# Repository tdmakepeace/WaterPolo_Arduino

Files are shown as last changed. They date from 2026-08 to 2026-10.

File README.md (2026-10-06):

# Water Polo Scoreboard (Arduino Mega)

Operator scoreboard for water polo: **period clock**, **home/away scores**, and a **28 s shot clock**. The shot clock is shown on the local RGB matrix and 16×2 LCD, and is broadcast to external LoRa remote shot clocks (`lora_remote`).

---

## Parts list

| Qty | Part | Notes / SKU |
| --- | --- | --- |
| 1 | Arduino Mega 2560 (or compatible) | Required — Uno does not have enough pins |
| 1 | Waveshare RGB LED matrix 64×32 P3 | **SKU 33840** — RGB-Matrix-P3-64x32 (HUB75) |
| 1 | 5 V power supply for matrix | **≥ 2.5 A** (Waveshare rating); VH4 connector |
| 1 | HUB75 16-pin IDC ribbon | Usually included with the panel |
| 1 | VH4 2-pin power cable | Usually included with the panel |
| 1 | **Freenove I2C IIC LCD 1602** | Serial 16×2 “New Type” (I2C backpack onboard) |
| 16  | Momentary push-buttons | Score / clock / shot / TO / IN / Return / excl  |
| 1 | **5 V relay module** (or 5 V coil + driver) | Driven by **D12**; switches horn / siren / lamp |
| 1 | LoRa UART module (TX side) | e.g. DX-LR02 / DX-LR32 433 MHz class |
| 1+  | LoRa remote shot-clock units | Sketch `lora_remote/lora_remote.ino`. Wiring: [docs/lora_remote_build.md](docs/lora_remote_build.md) |
| — | Dupont / jumper wires, breadboard or proto  | As needed |
| — | USB cable (A–B) | Mega programming / optional 5 V for MCU only |

**Optional:** level shifter if LoRa module is strictly 3.3 V on UART. For a bare relay coil (no PCB module), use an NPN/MOSFET driver and a flyback diode across the coil — do **not** drive a coil from a Mega pin directly.

---

## What it does

| Control | Pin | Action |
| --- | --- | --- |
| Period start / stop  | **D2**  | Short press toggles countdown (shot clock follows) |
| Force shot 18 | **D3**  | Set shot clock to 18 s always (ignores <18 rule); **pauses** period clock |
| Exclusion | **D4**  | Start 18 s exclusion; **1st press** clock 1, **2nd press** clock 2; **pauses** period clock; applies **D5** if shot <18 |
| Shot → 18 | **D5**  | Set shot to 18 if <18; period clock **unchanged** (stays running or stopped) |
| Shot → 28 | **D6**  | Shot→28; period clock **unchanged**; **clears exclusions** |
| Timeout 1:00 | **D7**  | Pause period + shot; run independent 1:00 timeout |
| Interval 2:00 | **D8**  | Advance period (P1→P4); load match period length + shot→28; keep remaining exclusions; run **IN** or **HT** |
| Relay (horn / alarm) | **D12** | Pulses when shot expires (~0.5 s) or period hits 0 (~1 s) |
| Return | **D35** | End **TO/IN/HT** early → period+shot (**keeps shot value** after timeout); also **exits timing menu** |
| Period +1 s | **D36** | Short +1 s · long press **+10 s** (max 8:00) |
| Period −1 s | **D37** | Short −1 s · long press **−30 s** (min 0:00) |
| Shot +1 s | **D38** | Short +1 s · long press **+10 s** (max 28) |
| Shot −1 s | **D39** | Short −1 s · long press **−10 s** (min 0) |
| Home + | **D40** | Home score +1; **stops** period clock; shot → **28**; **clears exclusions** |
| Home − | **D41** | Decrease home |
| Away + | **D42** | Away score +1; **stops** period clock; shot → **28**; **clears exclusions** |
| Away − | **D43** | Decrease away |

- **D2** short press → start/stop immediately (play mode only; behaviour depends on **CLOCK** STOP / RUN / RUN-NS)  
- Hold **D2** ~3 s → STOP mode (from stopped): reload period to match length · RUN / RUN-NS: stop the period  
- Hold **D2 + D35** ~**3 s** → reload period to match length; **keep** shot + exclusions  
- Hold **D2 + D6** together for **3 s** → **full reset** (scores 0–0, period **P1** 8:00, shot 28, clear TO/IN/HT/exclusions, clocks stopped; timing values + **CLOCK** back to defaults)
- Hold **D5 + D6** ~**3 s** → **timing menu** (PERIOD → INTERVAL → HALFTIME → TIMEOUT → SHOT 28 → SHOT 18 → CLOCK; **D36**/**D37** ±30 s, shot pages ±1 s, or CLOCK cycle STOP → RUN → RUN-NS, **S/S** next/confirm, **D35** exit)  
- Operator detail: [timing menu](docs/user_guide_timing_menu.md) · [STOP mode](docs/user_guide_stop_mode.md) · [RUN mode](docs/user_guide_run_mode.md)  
- Shot clock counts while **play** is active (in STOP mode that matches the period; in RUN mode period may keep running alone)  
- If period remaining is **less than** the shot clock, the shot shows the period seconds (matrix / LCD / LoRa)  
- Value adjust buttons do **not** start/stop the clocks  
- Shot value is sent to LoRa remotes on every change, and **re-broadcast every 0.5 s while play is running**  
- **Period length:** default `PERIOD_SECONDS` (**8:00**). If you change the period clock **before the first START** of that period, the new value becomes the match length and is reloaded by **INTERVAL** / period-reload for later periods (e.g. trim to **6:30** before kickoff → every period starts at 6:30). Adjustments **after** START only fix the live clock and do not change later periods.  
- **Timeout:** period and shot freeze; when TO ends (or **D35 Return**), display returns to period+shot with **same shot value**; resume with **D2**  
- **Interval:** advances the period counter (max **P4**); loads the match period length / shot **28**; **remaining exclusion time is kept** (paused during the break, resumes next period); after **P2** uses half-time (`HALF_TIME_SECONDS`, currently **2:00**, label **HT**), otherwise `INTERVAL_SECONDS` (**2:00**, label **IN**); when the break ends (or **D35 Return**), display returns to period+shot; start play with **D2**. Also starts automatically when the period clock reaches **0:00** in **P1–P3** (not after **P4**).  
- **Exclusions:** one button (**D4**) starts clock 1 then clock 2; each slot starts only from idle (0) and cannot be restarted until it reaches 0; pause during timeout/interval and when play is stopped; remaining time is **carried into the next period** across IN/HT; a **goal** (home+ / away+) or **D6** (shot → 28) clears both clocks

---

## How to use

This is the operator overview for the control panel (button box + LCD). Full button-by-button detail lives in the mode guides below — use those when training operators or when **CLOCK** is set to **RUN** or **RUN-NS**.

**Detailed operator guides:**

| Guide | Contents |
|---|---|
| [Timing menu](docs/user_guide_timing_menu.md) | Open/leave menu; PERIOD / INTERVAL / HALFTIME / TIMEOUT / SHOT 28 / SHOT 18 / CLOCK |
| [STOP mode (Start/Stop)](docs/user_guide_stop_mode.md) | Every button when **CLOCK = STOP** (default) |
| [RUN mode](docs/user_guide_run_mode.md) | Every button when **CLOCK = RUN** or **RUN-NS** (running period clock) |

Panel layout reference:

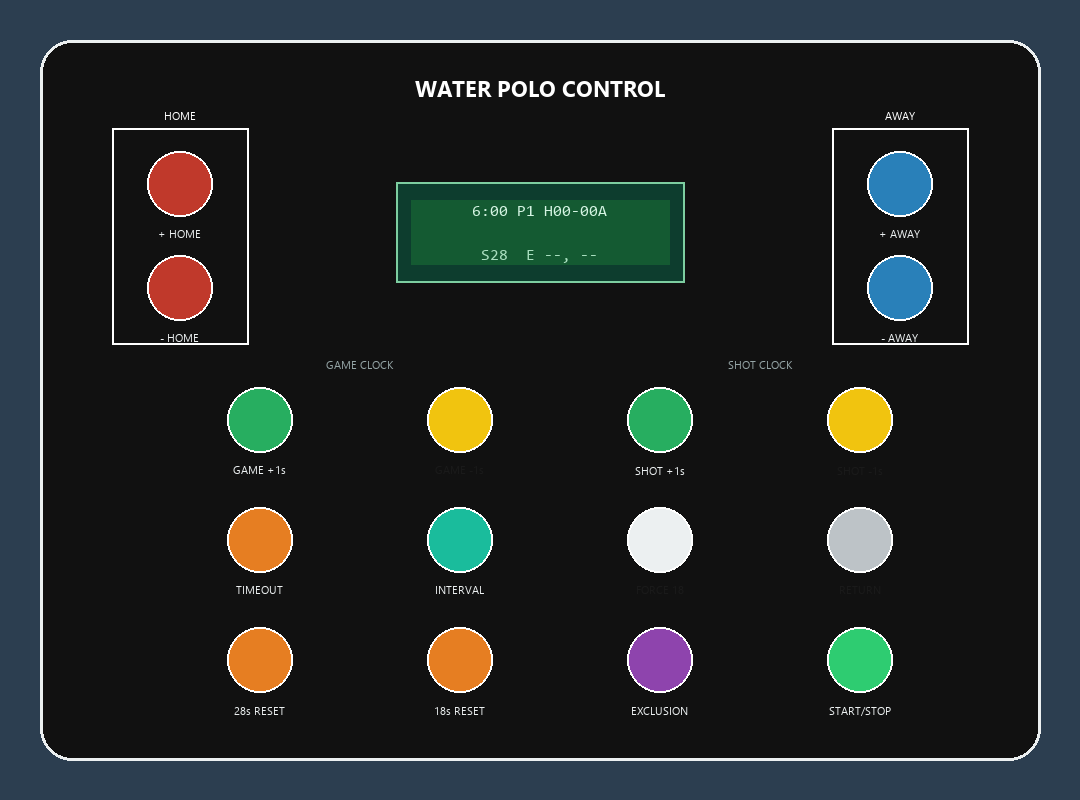
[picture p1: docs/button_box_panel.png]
Operator control panel button layout


Faceplate drill / 3D-print sizes (Ø16 mm buttons + Freenove 1602): `[docs/button_box_panel_measurements.md](docs/button_box_panel_measurements.md)`

### What you see

| Display | What it shows |
| --- | --- |
| LCD top line | Play: period time + `P#` + scores (`Hnn-nnA`). TO/IN/HT: break time + scores (no period) |
| LCD bottom line | Shot (`Snn`), run `*` (play active), exclusions `E-tt, tt`, command-ack `*` bottom-right |
| RGB matrix | Scores either side of `P#` (or `TO`/`IN`/`HT`), large centre clock, shot bottom-left, exclusions when active |

Defaults at power-up / full reset: scores **0–0**, period **P1** **8:00**, shot **28**, clocks **stopped**, **CLOCK = STOP**.

### Clock modes (STOP / RUN / RUN-NS)

Set on the timing-menu **CLOCK** page (see [timing menu guide](docs/user_guide_timing_menu.md)):

| Mode | Short **START/STOP** | Long **START/STOP** (~3 s) | Goal / EXCL / FORCE 18 / shot = 0 |
|---|---|---|---|
| **STOP** (default) | Toggle period + shot + exclusions together | From stopped: reload period to match length | Stops period + play |
| **RUN** | First start of quarter (or after timeout): start period + play. Later: toggle play only | Stops the period (+ play) | Period **keeps running**; play stops |
| **RUN-NS** | Same period rules as **RUN** | Same as **RUN** | Same as **RUN**, but shot clock disabled (hidden; shot buttons ignored) |

Hold **START/STOP** + **RETURN** ~**3 s** (either mode): reload period to match length; **keep** shot and exclusions; clocks stop.

### Start / stop (START/STOP) — STOP mode summary

| Action | Result |
| --- | --- |
| Short press **START/STOP** | Toggle period + shot + exclusions (play mode only) |
| While play runs | Period, shot, and exclusions count down |
| While play is stopped | Period, shot, and exclusions are frozen |
| Hold **START/STOP** ~3 s (from stopped) | Reset period clock to match length (does not start the clock) |

**START/STOP** does nothing during a timeout or interval / half-time — use **RETURN** first (or wait for the timer to finish).

For **RUN** / **RUN-NS** mode behaviour, see [docs/user_guide_run_mode.md](docs/user_guide_run_mode.md).

### Periods (P1–P4)

The board tracks the current period. Press **INTERVAL** at the end of a period to advance to the next (up to **P4**) and start the between-period break:

| Leaving | Break shown | Duration const (default) |
| --- | --- | --- |
| **P1** → **P2** | **IN** | `INTERVAL_SECONDS` (**2:00**) |
| **P2** → **P3** | **HT** | `HALF_TIME_SECONDS` (**2:00** for now; change to `5 * 60` for a 5-minute half-time) |
| **P3** → **P4** | **IN** | `INTERVAL_SECONDS` (**2:00**) |
| Already **P4**  | **IN** | stays on **P4**; same interval duration |

Full reset returns to **P1** and restores match length to **8:00**. Reloading the period clock (long-press **START/STOP** in STOP mode, or **START/STOP** + **RETURN**) does **not** change the period number.

### Scoring (HOME / AWAY)

| Button | Result (STOP mode) |
| --- | --- |
| **+ HOME** / **+ AWAY** | Score +1 (max 99); **stops** period + play; shot → **28**; **clears both exclusion clocks** |
| **− HOME** / **− AWAY** | Score −1 (min 0); clocks and shot are unchanged |

In **RUN** mode a goal still resets the shot and clears exclusions, but the **period keeps running**; only play stops. In **RUN-NS** the shot is disabled — goals only stop play and clear exclusions. Resume with **START/STOP**.

### Shot clock

| Button | Result (STOP mode) |
| --- | --- |
| **28s RESET** | Shot → **SHOT 28** length (default 28); run state unchanged; **clears both exclusion clocks** |
| **18s RESET** | Shot → **SHOT 18** length (default 18) only if current value is **shorter**; run state unchanged |
| **FORCE 18** | Shot → **SHOT 18** length always; **stops** period + play |
| Shot reaches **0** | Horn/relay (~0.5 s); remote buzzers; **clocks stop**; shot reloads to **SHOT 28** |

Lengths for **28s RESET** / **18s RESET** / **FORCE 18** are set on the timing-menu **SHOT 28** and **SHOT 18** pages.

In **RUN** mode, **FORCE 18** and shot expiry stop **play** only — the period keeps running.

When **period remaining** is less than the shot clock, the shot shows the period seconds on the matrix, LCD, and LoRa remotes. Period end takes precedence over shot expiry if both hit **0** together.

### Timeouts and intervals

| Button | Result |
| --- | --- |
| **TIMEOUT** | Pause period + play; run independent timeout (`TO`; length from menu) |
| **INTERVAL** | Advance period; load match length / **28**; keep exclusions; run **IN** or **HT** |
| **RETURN** short | End TO/IN/HT early (silent) → period + shot display |
| **RETURN** hold ~**3 s**  | During TO/IN/HT: end break **and** buzz. In play: buzz only |
| TO or IN/HT reaches **0** | Short horn/relay; display returns to period + shot automatically |

After timeout: shot value is **kept**; press **START/STOP** to resume.  
After interval / half-time: fresh period at match length / shot **28**; exclusions kept; press **START/STOP** to start play.

### Exclusions (EXCL)

| Button | Result (STOP mode) |
| --- | --- |
| **EXCL** (first press)  | Start exclusion **clock 1** (**18 s**); **stops** play; applies **18s RESET** rule if shot < 18 |
| **EXCL** (second press) | Start exclusion **clock 2** (same rules) while clock 1 is still running |

In **RUN** mode exclusions stop **shot/play** with the period still running (exclusions pause until **START/STOP**). In **RUN-NS** exclusions count down with the **period** clock.

Notes:

- Each slot starts only when it is **0** (idle). You cannot restart an active clock until it counts down to 0. If both are running, further presses do nothing.
- If clock 1 has expired and clock 2 is still running, the next press re-arms clock 1.
- Exclusion timers: **STOP** and **RUN** — tick with shot/play (pause when play stops and during TO/IN/HT). **RUN-NS** — tick with the period clock (pause during TO/IN/HT only).
- Remaining exclusion time is **carried into the next period** across **IN**/**HT** (auto at 0:00 or **INTERVAL**).
- A **goal** (**+ HOME** / **+ AWAY**) or **28s RESET** clears **both** exclusion clocks.
- Press **START/STOP** to resume play (and continue the exclusion countdown).

### PC-driven mode (WaterPoloScoreBoard over USB)

The Mega can act as a display + LoRa relay for the PC app [WaterPoloScoreBoard](https://github.com/tdmakepeace/WaterPoloScoreBoard). Plug the Mega's USB into the PC and pick its COM port on the app's **Settings** page. Matrix and LoRa wiring stay the same.

The app sends a newline-terminated frame at **9600** baud every **0.25 s**:

```text
HH,AA,PERIOD,CLOCK,SHOT,EX1,EX2      e.g. 03,01,P2,245,18,12,0
```

| Field | Meaning |
|---|---|
| `HH`, `AA` | Home / away score (0–99) |
| `PERIOD` | `P1`–`P4`, or `TO` / `IN` / `HT` |
| `CLOCK` | Period clock seconds; during `TO` / `IN` / `HT` the break countdown (shown in the large centre clock) |
| `SHOT` | Shot clock seconds |
| `EX1`, `EX2` | Exclusion clocks in seconds (`0` = hidden) |

- The **first valid frame** switches the board to PC-driven mode until power-cycle / reset: buttons and the local clocks are ignored, and the matrix and LCD show exactly what the PC sends. During `TO` the period clock shown bottom-right is the last value sent in play.
- The shot value is sent to the LoRa remotes when it changes and repeated every **0.5 s** while frames keep arriving (stops ~2 s after the PC goes quiet).
- Other lines from the PC are forwarded to LoRa unchanged: `BUZZER` (also pulses the D12 relay ~0.5 s), `END` / `CHANGE` (relay ~1 s), `TEST`, `exit`. Bare shot integers are ignored in PC-driven mode (the frame owns the shot); before the first frame they are relayed as-is, so the Mega also works as a plain LoRa relay.

### Timing menu (PERIOD / INTERVAL / HALFTIME / TIMEOUT / SHOT 28 / SHOT 18 / CLOCK)

Hold **18s RESET** and **28s RESET** for ~**3 s**. Clocks freeze while the menu is open. Values are kept until a **full reset** (not stored in EEPROM).

Full detail: [docs/user_guide_timing_menu.md](docs/user_guide_timing_menu.md)

| Order | Item | Default | Range |
|---|---|---|---|
| 1/7 | **PERIOD** | 8:00 | 0:30–15:00 (±30 s) |
| 2/7 | **INTERVAL** | 2:00 | 0:00–3:00 (±30 s) |
| 3/7 | **HALFTIME** | 2:00 | 0:00–7:00 (±30 s) |
| 4/7 | **TIMEOUT** | 1:00 | 0:30–5:00 (±30 s) |
| 5/7 | **SHOT 28** | 28 s | 1–60 s (±1 s) |
| 6/7 | **SHOT 18** | 18 s | 1–60 s (±1 s) |
| 7/7 | **CLOCK** | **STOP** | **STOP**, **RUN**, or **RUN-NS** (cycle) |

| Button | In menu |
|---|---|
| Game **+1s** / **−1s** | Current time **±30 s**, shot pages **±1 s**, or cycle **CLOCK** STOP → RUN → RUN-NS |
| **START/STOP** (LCD shows **S/S**) | Next item; on **CLOCK** confirm and **exit** |
| **RETURN** | Exit immediately (keeps changes already made) |

LCD: `SET PERIOD  1/7` / `8:00  S/S next`. Shot pages show `28s` / `18s`. Last page shows `S/S OK`. Other buttons are ignored until you leave the menu.

If the current period has not been started yet, changing **PERIOD** also updates the live period clock. **SHOT 28** / **SHOT 18** set the lengths used by **28s RESET**, **18s RESET**, **FORCE 18**, goals, interval, and shot expiry.

### Fine adjust (GAME CLOCK / SHOT CLOCK ±1s)

Use these to correct time without starting or stopping play yourself (they do not toggle the clocks):

| Button | Short press | Long press (~0.8 s) |
| --- | --- | --- |
| Game **+1s** | Period +1 s | Period **+10 s** |
| Game **−1s** | Period −1 s | Period **−30 s** |
| Shot **+1s** / **−1s** | Shot ±1 s | Shot ±10 s |

Limits: period **0:00–15:00** (live ±1 s; match length comes from the timing menu / pre-START trim), shot **0** to the current **SHOT 28** value. Period adjust only works in play mode (not during TO/IN). If you adjust period to **0:00**, the clocks stop.

If you change the period clock **before the first START** of the current period, that value becomes the **match length** used for later periods.

### Full game reset

Hold **START/STOP** and **28s RESET** together for **~3 s**:

- Scores → **0–0**
- Period → **P1** **8:00**, shot → **28**
- Timing lengths → defaults (period **8:00**, interval **2:00**, half-time **2:00**, timeout **1:00**, shot **28** / **18**)
- **CLOCK** → **STOP**
- Clears timeout / interval / half-time / exclusions / timing menu
- Clocks stopped

### Typical period workflow (STOP mode)

1. Confirm scores and clocks (or do a full reset). Optionally set **CLOCK** in the timing menu.
2. Press **START/STOP** to begin the period.
3. On a shot-clock reset foul / new possession → **28s RESET** (or **18s RESET** / **FORCE 18** as required).
4. On a goal → **+ HOME** or **+ AWAY** (clock stops, shot → 28, exclusions clear); resume with **START/STOP**.
5. On exclusion → **EXCL** (first press clock 1, second press clock 2), then **START/STOP** when play resumes.
6. Team timeout → **TIMEOUT**; when done (or **RETURN**), **START/STOP** to resume.
7. Between periods → **INTERVAL** (after **P2** this is **HT**); when done, **START/STOP** for the next period.
8. If the period hits **0:00**, the horn sounds (~1 s) and remotes get `END`. **P1–P3** then auto-start the **IN**/**HT** break (same as **INTERVAL**); **P4** stays at **0:00**.

For the **RUN** mode workflow, see [docs/user_guide_run_mode.md](docs/user_guide_run_mode.md).

### Button quick reference

| Panel label | Function |
| --- | --- |
| **START/STOP** | Start/stop (STOP: all clocks; RUN: see mode guide) |
| **+ HOME** / **− HOME** | Home score ±1 (+ also stops play, shot → 28, clears exclusions)  |
| **+ AWAY** / **− AWAY** | Away score ±1 (+ also stops play, shot → 28, clears exclusions)  |
| **28s RESET** | Shot → 28; clears exclusions |
| **18s RESET** | Shot → 18 if < 18 |
| **FORCE 18** | Shot → 18 always; stops play (period too in STOP mode) |
| **TIMEOUT** | Team timeout (length from menu) |
| **INTERVAL** | Next period + IN/HT break (fresh match length / 28; exclusions kept) |
| **RETURN** | Leave TO/IN/HT / menu; long ≈ buzz; with S/S ≈ period reload |
| **EXCL** | 18 s exclusion timers (press 1 → clock 1, press 2 → clock 2) |
| Game **+1s** | Period +1 s (hold **+10 s**); in timing menu **+30 s** / shot pages **+1 s** / CLOCK cycle |
| Game **−1s** | Period −1 s (hold **−30 s**); in timing menu **−30 s** / shot pages **−1 s** / CLOCK cycle |
| Shot **±1s** | Shot ±1 s (hold ±10 s) |
| Hold **18s + 28s** ~3 s | Timing menu (PERIOD / INTERVAL / HALFTIME / TIMEOUT / SHOT 28 / SHOT 18 / CLOCK) |
| Hold **S/S + 28s** ~3 s | Full game reset |
| Hold **S/S + RETURN** ~3 s | Reload period length; keep shot + exclusions |

---

## Libraries

Matrix driver files are **vendored** in `waterpolo_scoreboard/`: `RGBmatrixPanel`, `Adafruit_GFX`, `gamma.h`, `gfxfont.h`, `glcdfont.c`, `Fonts/fonts.h`. The sketch calls Waveshare `Reginit()` **before** `matrix.begin()`. You do not need the Library Manager Adafruit GFX / RGB matrix Panel packages for the scoreboard sketch.

Arduino IDE → **Tools → Manage Libraries**:

1. **LiquidCrystal I2C** (e.g. by Frank de Brabander), or Freenove’s `LiquidCrystal_I2C.zip` from their kit docs

**Board:** Tools → Board → **Arduino Mega or Mega 2560**

I2C address: sketch tries **0x27** (PCF8574T), then **0x3F** (PCF8574AT) automatically.

---

## Full Arduino Mega pin map

Status legend: **USED** = wired by this project · **RESERVED** = claimed by the matrix library (leave free) · **SPARE** = available for expansion · **AVOID** = prefer not to use

### Digital pins D0–D53

| Pin | Status | Connection / notes |
| --- | --- | --- |
| D0  | AVOID | Serial RX0 (USB serial) — leave free for programming/debug |
| D1  | AVOID | Serial TX0 (USB serial) — leave free for programming/debug |
| D2  | USED | Button — period clock start / stop |
| D3  | USED | Button — **force shot → 18** (pauses period clock) |
| D4  | USED | Button — **exclusion** (18 s, no reset; 1st press clock 1, 2nd press clock 2) |
| D5  | USED | Button — shot clock → 18 s (if < 18) |
| D6  | USED | Button — shot clock → 28 s (clears exclusions) |
| D7  | USED | Button — **timeout 1:00** |
| D8  | USED | Button — **interval / half-time** (advances period) |
| D9  | USED | Matrix HUB75 **LAT / STB** |
| D10 | USED | Matrix HUB75 **OE** |
| D11 | USED | Matrix HUB75 **CLK** (must be on PORTB) |
| D12 | USED | **5 V relay** IN (default HIGH = ON; see `RELAY_ACTIVE_HIGH`) |
| D13 | SPARE | Also onboard LED — usable if LED flash is acceptable |
| D14 | SPARE | Serial3 TX — free unless you need Serial3 |
| D15 | SPARE | Serial3 RX — free unless you need Serial3 |
| D16 | SPARE | Serial2 TX — free unless you need Serial2 |
| D17 | SPARE | Serial2 RX — free unless you need Serial2 |
| D18 | USED | LoRa module **RX** ← Mega **TX1** (Serial1) |
| D19 | USED | LoRa module **TX** → Mega **RX1** (Serial1) |
| D20 | USED | Freenove LCD **SDA** (I2C) |
| D21 | USED | Freenove LCD **SCL** (I2C) |
| D22 | RESERVED | Matrix library (PORTA) — **do not use** |
| D23 | RESERVED | Matrix library (PORTA) — **do not use** |
| D24 | USED | Matrix HUB75 **R1** |
| D25 | USED | Matrix HUB75 **G1** |
| D26 | USED | Matrix HUB75 **B1** |
| D27 | USED | Matrix HUB75 **R2** |
| D28 | USED | Matrix HUB75 **G2** |
| D29 | USED | Matrix HUB75 **B2** |
| D30 | SPARE | Was parallel LCD RS — free with I2C LCD |
| D31 | SPARE | |
| D32 | SPARE | |
| D33 | SPARE | |
| D34 | SPARE | Was interval — now **D8** |
| D35 | USED | Button — **RETURN** (end TO/IN) |
| D36 | USED | Button — period clock **+1 s** (long **+10 s**) |
| D37 | USED | Button — period clock **−1 s** (long **−30 s**) |
| D38 | USED | Button — shot clock **+1 s** |
| D39 | USED | Button — shot clock **−1 s** |
| D40 | USED | Button — home score + |
| D41 | USED | Bu tton — home score − |
| D42 | USED | Button — away score + |
| D43 | USED | Button — away score − |
| D44 | SPARE | PWM-capable |
| D45 | SPARE | PWM-capable |
| D46 | SPARE | |
| D47 | SPARE | |
| D48 | SPARE | |
| D49 | SPARE | |
| D50 | SPARE | SPI MISO — free unless using SPI |
| D51 | SPARE | SPI MOSI — free unless using SPI |
| D52 | SPARE | SPI SCK — free unless using SPI |
| D53 | SPARE | SPI SS — free unless using SPI |

### Analog pins A0–A15 (also usable as digital)

| Pin | Status | Connection / notes |
| --- | --- | --- |
| A0  | USED | Matrix HUB75 address **A** |
| A1  | USED | Matrix HUB75 address **B** |
| A2  | USED | Matrix HUB75 address **C** |
| A3  | USED | Matrix HUB75 address **D** |
| A4  | SPARE  | |
| A5  | SPARE  | |
| A6  | SPARE  | |
| A7  | SPARE  | |
| A8  | SPARE  | |
| A9  | SPARE  | |
| A10 | SPARE  | |
| A11 | SPARE  | |
| A12 | SPARE  | |
| A13 | SPARE  | |
| A14 | SPARE  | |
| A15 | SPARE  | |

### Spare pins summary (quick list)

**Digital:** D13, D14, D15, D16, D17, D30, D31, D32, D33, D34, D44, D45, D46, D47, D48, D49, D50, D51, D52, D53  

**Analog / digital:** A4, A5, A6, A7, A8, A9, A10, A11, A12, A13, A14, A15  

**Do not use:** D0, D1 (USB serial), D22, D23 (matrix library)

---

## Wiring diagram

### Operator control panel

Suggested faceplate layout for the operator box (buttons + I2C LCD):

Operator control panel button layout

**3D-print / CNC measurements** (Ø16 mm buttons + Freenove I2C LCD 1602): see `[docs/button_box_panel_measurements.md](docs/button_box_panel_measurements.md)` — panel **250 × 180 mm**, LCD bezel cutout **72 × 25 mm**, full hole-centre table and SVG. Printable mesh: `[docs/button_box_panel_faceplate.stl](docs/button_box_panel_faceplate.stl)`.

| Position | Control | Pin |
| --- | --- | --- |
| Top left | Home + / − | **D40** / **D41** |
| Top right | Away + / − | **D42** / **D43** |
| Center | I2C LCD 16×2 | **SDA D20** / **SCL D21** |
| Row 1 (under LCD) | Game +1s · Game −1s · Shot +1s · Shot −1s | **D36** · **D37** · **D38** · **D39** |
| Row 2 | Timeout · Interval · Force 18 · Return | **D7** · **D8** · **D3** · **D35** |
| Row 3 | 28s Reset · 18s Reset · Exclusion · Start/Stop | **D6** · **D5** · **D4** · **D2** |

### RGB matrix → Mega (HUB75)

Confirmed for **Waveshare RGB-Matrix-P3-64x32** (SKU **33840**) with the vendored Waveshare `RGBmatrixPanel` driver on **Arduino Mega 2560** — pin numbers and ribbon colours match the working `waterpolo_scoreboard/` sketch. Data lines **R1…B2** are fixed on **D24–D29** (`PORTA`); address **A0–A3**, **CLK D11**, **LAT D9**, **OE D10**. Rainbow ribbon: **yellow #14 → LAT D9**, **green #15 → OE D10**. Pin 8 on this 64×32 HUB75 is **GND** (grey #8) — not address **E**.

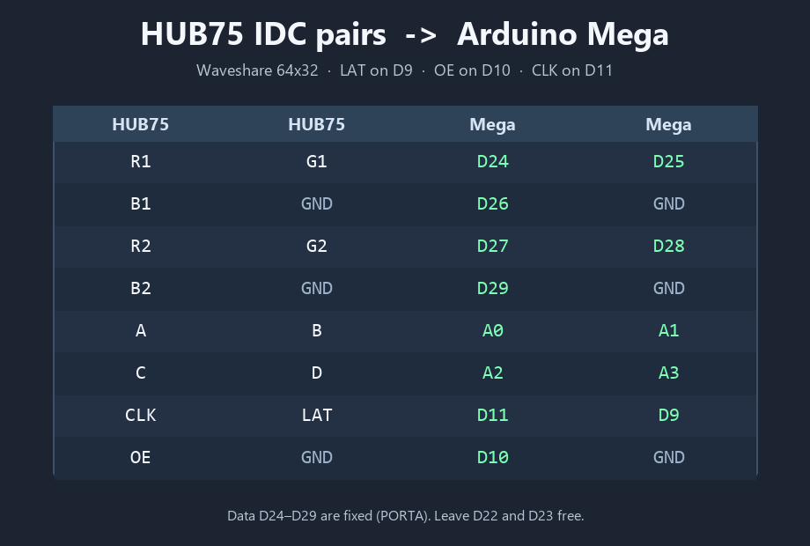
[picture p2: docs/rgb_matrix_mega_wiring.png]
RGB Matrix HUB75 wiring to Arduino Mega


HUB75 IDC pairs (as on the connector) → Mega:

| HUB75 | Mega | HUB75 | Mega |
| ----- | --- | --- | --- |
| R1 | **D24** | G1 | **D25** |
| B1 | **D26** | GND | **GND** |
| R2 | **D27** | G2 | **D28** |
| B2 | **D29** | GND | **GND** |
| A | **A0**  | B | **A1**  |
| C | **A2**  | D | **A3**  |
| CLK | **D11** | LAT / STB | **D9**  |
| OE | **D10** | GND | **GND** |

Power: **VH4 VCC / GND** → **external 5 V ≥2.5 A PSU** (not Mega 5 V).

Leave **D22** and **D23** free — the matrix library writes the full `PORTA` register.

#### Rainbow ribbon colours (16-way, brown = pin 1)

On a rainbow flat IDC ribbon, **brown is conductor 1** (= HUB75 **R1**). Align the brown edge with the pin-1 mark on the HUB75 header (often a triangle / arrow on the moulding). Colours then follow in order:

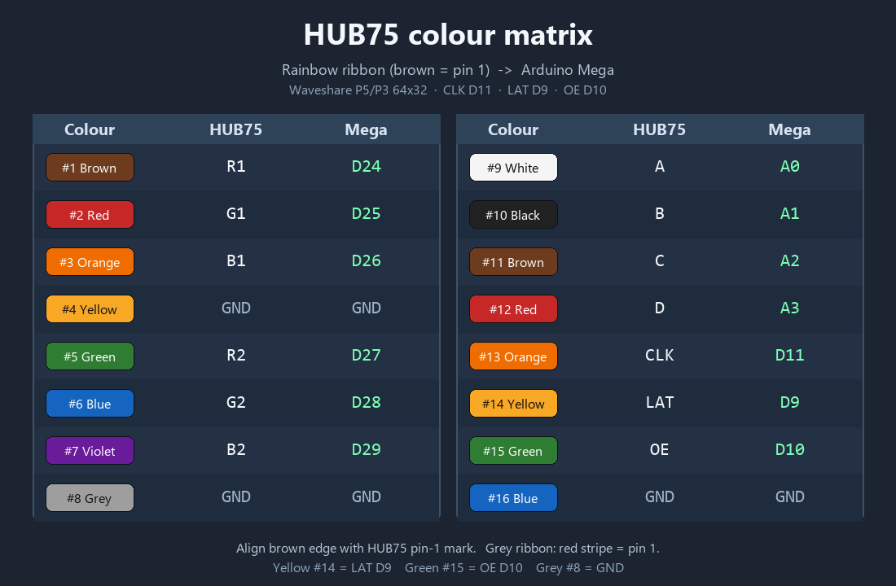
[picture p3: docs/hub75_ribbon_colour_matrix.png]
HUB75 rainbow ribbon colour matrix


| # | Colour | HUB75 | Mega |
| --- | --- | ----- | --- |
| 1 | Brown  | R1 | **D24** |
| 2 | Red | G1 | **D25** |
| 3 | Orange | B1 | **D26** |
| 4 | Yellow | GND | **GND** |
| 5 | Green  | R2 | **D27** |
| 6 | Blue | G2 | **D28** |
| 7 | Violet | B2 | **D29** |
| 8 | Grey | GND | **GND** |
| 9 | White  | A | **A0** |
| 10  | Black  | B | **A1** |
| 11  | Brown  | C | **A2** |
| 12  | Red | D | **A3** |
| 13  | Orange | CLK | **D11** |
| 14  | Yellow | LAT | **D9** |
| 15  | Green  | OE | **D10** |
| 16  | Blue | GND | **GND** |

Grey ribbons with a **red stripe** mark pin 1 the same way (stripe = R1 / brown above).

### Full system overview

```text
                         +---------------------------+
                         |     5 V / ≥2.5 A PSU      |
                         |  (+) -------------- (-)   |
                         +-------|------|------+-----+
                                 |      |
                                 |      +---- common GND ----+
                                 |                           |
                                 v                           v
                    +------------------------+      +------------------+
                    | Waveshare 64x32 Matrix |      |  Arduino Mega    |
                    | VH4: VCC / GND         |      |  2560            |
                    | HUB75 INPUT (IDC)      |      |                  |
                    +-----------+------------+      |  USB (PC)        |
                                |                   |                  |
           HUB75 ribbon                                         |                   |  Buttons         |
                                |                   |  Relay D12       |
                                |                   |  I2C LCD 20/21   |
                                |                   |  Serial1 18/19   |
                                v                   +--------+---------+
                    R1->24  G1->25  B1->26                   |
                    R2->27  G2->28  B2->29                   |
                    A->A0   B->A1   C->A2   D->A3            |
                    LAT->9  OE->10 CLK->11  GND->GND        |
                                                             |
              +------------------+     +---------------------+--+
              | Freenove I2C     |     | LoRa TX module       |
              | LCD 1602         |     | RX  <- Mega 18 (TX1) |
              | GND -> GND       |     | TX  -> Mega 19 (RX1) |
              | VCC -> 5V        |     | GND <-> Mega GND     |
              | SDA -> 20        |     | VCC = 3V3/5V (datasheet) |
              | SCL -> 21        |     +----------+-----------+
              +------------------+                |
                                                  |  RF @ 433 MHz
                                                  v
                                               LoRa remotes
                                               (lora_remote)

  Buttons (each: Mega pin ----- button ----- GND)
    D2  period start/stop
    D3  force shot 18
    D4  exclusion (press 1 → clock 1, press 2 → clock 2)
    D5  shot → 18 (if < 18)     D6  shot → 28
    D7  timeout 1:00
    D8  interval 2:00  D35 RETURN
    D36 period +1s (+10 long)    D37 period -1s (-30 long)
    D38 shot +1s      D39 shot -1s
    D40 home+     D41 home-
    D42 away+     D43 away-

  Relay (5 V module — preferred):
    Mega 5V  ----- VCC (JD-VCC jumper on if module supports it)
    Mega GND ----- GND
    Mega D12 ----- IN   (signal)
    COM/NO/NC ---- wire to your horn / siren / lamp supply (isolated from Mega)

  Bare 5 V relay coil (not recommended without a driver):
    Use a transistor or MOSFET + flyback diode across the coil.
    Mega pin cannot source coil current safely.

  If the module is "active LOW" (LED on when IN is grounded), set in the sketch:
    const bool RELAY_ACTIVE_HIGH = false;
```

### Power rules

1. Power the **matrix from the external 5 V supply** on the **VH4** connector — never from the Mega 5 V pin.
2. Tie **PSU GND**, **Mega GND**, **matrix GND**, **LCD GND**, **LoRa GND**, and **button commons** together.
3. Mega may be powered by USB during development; for stand-alone use a separate Mega supply (USB power bank / VIN) is fine.

---

## Build & upload instructions

1. **Assemble power first** — connect the matrix VH4 cable to the 5 V / ≥2.5 A supply and common GND **before** plugging in the HUB75 ribbon for long sessions.
2. **Wire HUB75** exactly as in the pin map (data lines **must** be 24–29).
3. **Wire buttons** D2–D8, D35–D43 to GND (internal pull-ups; pressed = LOW).
4. **Wire Freenove I2C LCD** — **GND→GND**, **VCC→5V**, **SDA→D20**, **SCL→D21**. Contrast/backlight are onboard (no pot needed).
5. **Wire the 5 V relay** to **D12** (see relay wiring above). Set `RELAY_ACTIVE_HIGH` to match your module.
6. **Wire LoRa** module to Serial1 (18/19) and set `LORA_DEFAULT_CHANNEL` in the sketch to match remotes (default **2** = 433.150 MHz).
7. Open `waterpolo_scoreboard/waterpolo_scoreboard.ino` (matrix driver files are already in that folder).
8. Tools → Board → **Arduino Mega or Mega 2560**, select the correct COM port.
9. Upload, then power the matrix supply and reboot/reset the Mega.

### First-run checks

| Check | Expected |
| --- | --- |
| LCD | `8:00 P1 H00-00A` / `S28 E---, --` |
| Matrix | Scores `00` |
| D2 short press | Clocks run (`*` on LCD); shot counts down with period |
| D6 | Shot → 28 on LCD, matrix, and remotes |
| D5 with shot < 18 | Shot → 18; if ≥ 18, unchanged |
| D36 / D37 | Period time ±1 s (long: **+10** / **−30**) |
| D38 / D39 | Shot time ±1 s (updates remotes) |
| Clock running | Remotes update ~every **0.5 s** |
| Shot → 0 | LoRa `0` + `BUZZER`; local relay ~0.5 s; **clocks stop**; shot resets to **28** |
| Period → 0 | Relay ~1 s; LoRa `END`; **P1–P3** auto **IN**/**HT**; **P4** stays at 0:00 |

If RGB colours look wrong (G/B swapped on some panels), swap the physical **G1↔B1** and **G2↔B2** wires.

---

## Displays

### LCD (Freenove I2C 1602)

Play:

```text
8:00 P1 H03-02A
S28* E-18, 12  *
```

- Top (play): period time · `P#` · `H` home `-` away `A`
- Top (TO/IN/HT): break label + time · scores only (period hidden)
- Bottom: `S` shot · `*` if period running · `E-` + first excl · `,`  · second excl (`--` if idle) · `*` flashes (~0.3 s) bottom-right on command ack

Timeout / interval / half-time:

```text
TO 0:45 H03-02A
S28  E---, --  *
```

```text
IN 1:30 H03-02A
S28  E---, --   
```

```text
HT 1:30 H03-02A
S28  E---, --   
```

Defaults / first-run LCD expect: `8:00 P1 H00-00A` / `S28  E---, --`

### RGB matrix (64×32)

RGB matrix play-mode layout example

Play:

```text
03      P1      02
      5:42
28     e1 e2
```

Timeout (`TO`) / interval (`IN`) / half-time (`HT`):

- Top centre label becomes `TO` / `IN` / `HT` (instead of `P#`)
- Large middle clock shows the break countdown
- Shot stays bottom-left (red)
- On **TO** only: frozen period clock is copied to the bottom-right next to the shot

```text
03      TO      02
      0:45
28              5:42
```

- Home score white, away score medium blue (no H/A labels)  
- Labels (`P#` / `TO` / `IN` / `HT`) orange  
- Main clock: white >1:00, orange ≤1:00 down to 0:29, red ≤0:28 (blinks at 0:00)  
- Shot always red  
- Exclusions magenta (play and IN/HT, while > 0)

---

## LoRa protocol (remote shot clocks)

Compatible with `lora_remote/lora_remote.ino` and `lora_remote/scoreboard_commands.h`. Wiring for one remote: [docs/lora_remote_build.md](docs/lora_remote_build.md).

| Item | Value |
| --- | --- |
| Link | Mega **Serial1** @ **9600** baud (`LORA_BAUD`) |
| Framing | Newline-terminated text |
| Shot value | Decimal string `28`, `18`, `0`, … |
| Shot expired | `0` then `BUZZER`, then master stops clocks and reloads shot to `28` |
| Period expired | `END` |
| While running  | Re-send current shot value every **0.5 s** |
| Channel table  | CH0–3 → 433.050 / .100 / .150 / .200 MHz |

Remotes must use the **same** `LORA_DEFAULT_CHANNEL` as this master.

---

## Freenove I2C LCD notes

| LCD pin | Mega |
| --- | --- |
| GND | GND |
| VCC | 5 V |
| SDA | **D20** |
| SCL | **D21** |

- Library: **LiquidCrystal_I2C**
- Address auto-select: `0x27` then `0x3F`
- Pins **D30–D34** are free (no longer used for parallel LCD / old interval pin); **D8** / **D35** are Interval / Return

---

## Quick hardware test

### RGB matrix (HUB75)

Use the scoreboard sketch (`waterpolo_scoreboard/waterpolo_scoreboard.ino`) to confirm the panel. At startup it fills the matrix red, then clears.

> **Power first (required).** The panel must be powered from the **external 5 V ≥2.5 A** supply on the **VH4** connector, with **PSU GND** tied to **Mega GND**.  
> Do **not** judge the display with only USB/Mega power. With no VH4 supply, the ribbon can still weakly light some LEDs (often a **red** strip on the left) by leaking current through the data pins — that is **parasitic power**, can stress the Mega, and is **not** a valid test result.

1. Connect **VH4** to the external **5 V ≥2.5 A** PSU (**VCC** and **GND**); tie **PSU GND** to **Mega GND**
2. Wire the HUB75 ribbon exactly as in [RGB matrix → Mega (HUB75)](#rgb-matrix--mega-hub75) (brown = pin 1 / R1 → **D24**, …)
3. Open `waterpolo_scoreboard/waterpolo_scoreboard.ino`, select **Arduino Mega or Mega 2560**, upload
4. The panel should flash **red**, then show the scoreboard (home score, period, away score, clock, shot)

**If a red strip shows with VH4 unplugged:** expected parasitic glow — connect proper VH4 power before debugging further.

**If top half is solid red but bottom half flashes / is unstable (cables already checked):**

1. Confirm the ribbon is in the panel **HUB75 INPUT** (often labelled **IN** / arrow in) — **not** the OUTPUT / cascade port
2. Measure **5 V at the VH4 connector while the red screen is on** — if it sags below ~4.5 V, the PSU or wiring is too weak (use ≥2.5 A, short thick leads)
3. Grey #8 is **GND** on this 64×32 panel — wire it to **Mega GND**, not A4

**If blue looks solid but red/green are scattered or “short”:** the blue wires are probably fine; re-check these Mega pins / ribbon colours:

| Channel | HUB75 | Mega | Rainbow colour |
| --- | ----- | --- | --- |
| R1 | R1 | **D24** | Brown (#1) |
| G1 | G1 | **D25** | Red (#2) |
| R2 | R2 | **D27** | Green (#5) |
| G2 | G2 | **D28** | Blue (#6) |

**If colours are swapped** (e.g. green↔blue): swap physical **G1↔B1** and **G2↔B2**, then re-run the test.

**If the panel is blank / scrambled / full white with VH4 powered:** check common GND, **CLK on D11**, **LAT D9**, **OE D10**, grey #8 to **GND**, and data on **D24–D29**. Ribbon: **yellow #14 → LAT D9**, **green #15 → OE D10** (as in `waterpolo_scoreboard/`). Confirm `Reginit()` runs before `matrix.begin()`.

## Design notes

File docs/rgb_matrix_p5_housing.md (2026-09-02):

# P5 64×32 matrix housing — build template

Shallow rear box that holds a [Waveshare RGB-Matrix-P5-64x32](https://www.waveshare.com/rgb-matrix-p5-64x32.htm) (SKU **25848**) with a small cable cavity. The **HUB75 ribbon** and **VH4 power** leave through the **rear panel**. The LED face is the front of the assembly — do not put a bezel over the pixels.

This housing is for the **P5 320×160 mm** panel only. A P3 64×32 is 192×96 mm and will not fit.

Wiki: [RGB-Matrix-Px-64x32 (P5 variant)](https://docs.waveshare.com/RGB-Matrix-Px-64x32?variant=P5-64x32)

Related: [HUB75 wiring](rgb_matrix_mega_wiring.png) · [button-box faceplate](button_box_panel_measurements.md)

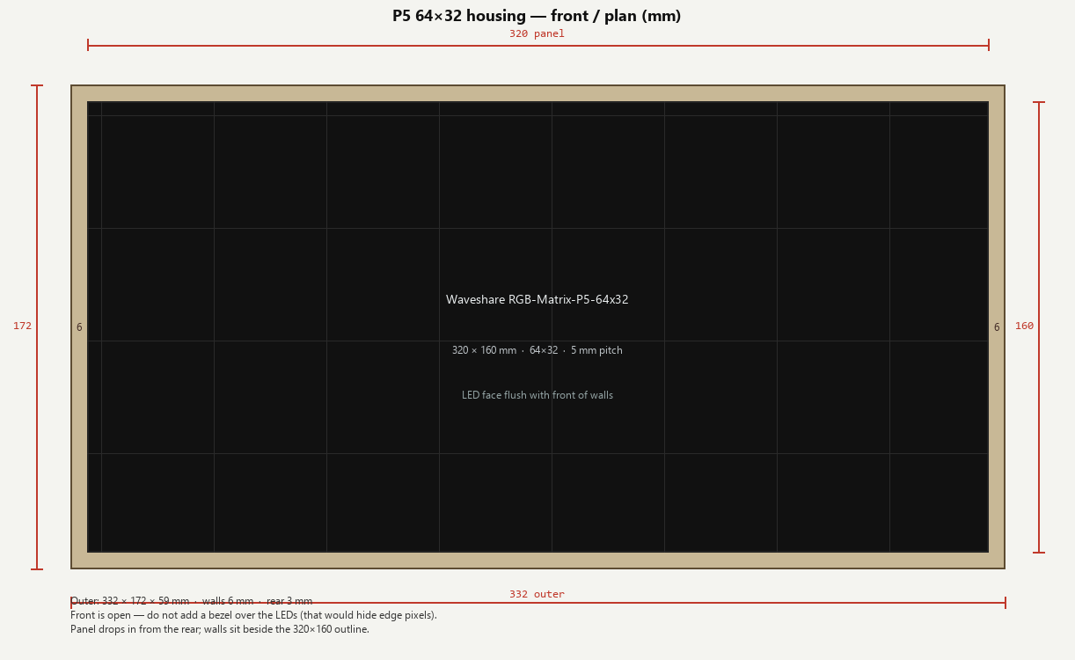
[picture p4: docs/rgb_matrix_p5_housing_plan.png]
Front / plan


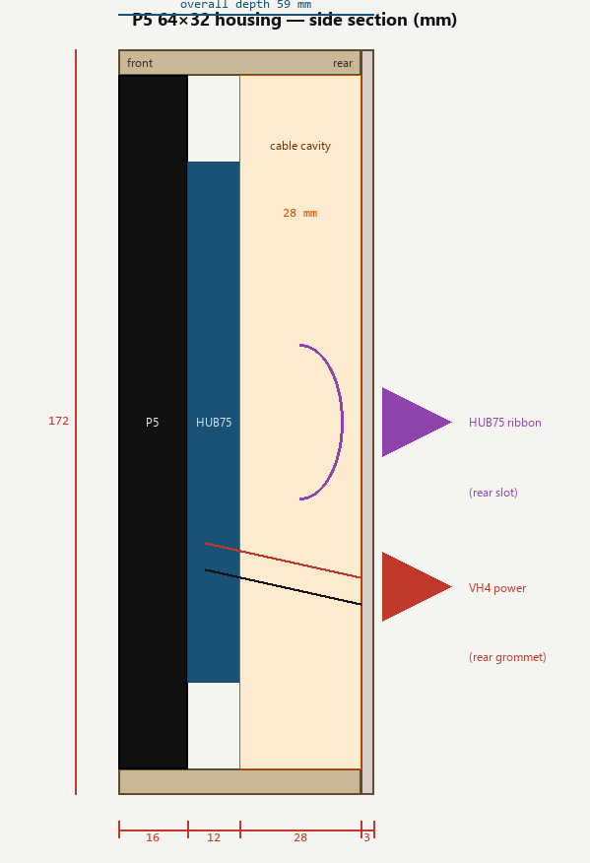
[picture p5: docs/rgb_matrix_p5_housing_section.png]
Side section


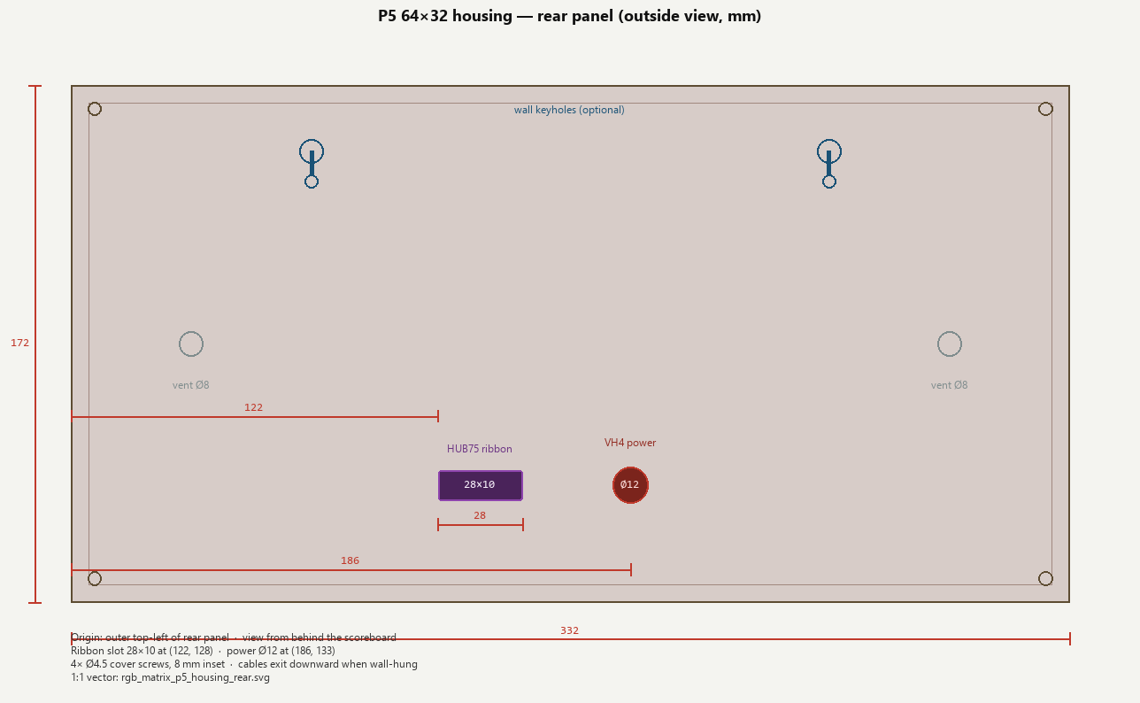
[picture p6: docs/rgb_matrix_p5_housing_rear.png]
Rear panel


1:1 rear-panel vector (laser / CNC): [`rgb_matrix_p5_housing_rear.svg`](rgb_matrix_p5_housing_rear.svg)

Regenerate drawings:

```bash
python docs/generate_p5_housing.py
```

---

## What this box does

| Goal | How |
|---|-----|
| Hold the matrix | 6 mm walls around a **320 × 160 mm** rear-loading pocket. LED face flush with the front. |
| Stash cables | **28 mm** cavity behind the HUB75 sockets for a folded ~30 cm ribbon and the VH4 pigtail. |
| Rear access | Removable rear panel with a **ribbon slot** and a **power grommet**. PSU and Mega stay outside the box. |

The Mega, button box, and 5 V PSU are **not** inside this housing.

---

## Panel (confirm on the unit)

| Item | Spec |
|---|---|
| Part | Waveshare **RGB-Matrix-P5-64x32** |
| SKU | **25848** |
| Face size | **320 × 160 mm** (64×32 × 5 mm pitch) |
| Typical thickness (LED + PCB) | **~16 mm** — measure yours |
| Typical rear protrusion (HUB75 / ICs / magnets) | **~12 mm** — measure yours |
| Headers | HUB75 **IN** + **OUT**, **VH4** 5 V power |
| Supply | **5 V / 4 A** (≤20 W). Never from Mega 5 V. |
| Weight | 0.665 kg |
| In the box | 16-pin ribbon ~30 cm, power terminal adapter |

> **Measure before cutting.** Waveshare notes that back-side layout can differ between batches. Fill in the table below from *your* panel, then drill magnet / screw posts to match.

### Measure-your-panel checklist

Place the panel **face down**. Origin = PCB **top-left** as viewed from the rear (HUB75 labels readable).

| Feature | Measured (mm) |
|---|---|
| Overall W × H | 320 × 160 (expect) · yours: ______ × ______ |
| LED + PCB thickness | ______ |
| Tallest rear part (socket / magnet) | ______ |
| HUB75 **IN** centre (X, Y) | ______ , ______ |
| VH4 power centre (X, Y) | ______ , ______ |
| Magnet / screw 1 (X, Y) | ______ , ______ |
| Magnet / screw 2 | ______ , ______ |
| Magnet / screw 3 | ______ , ______ |
| Magnet / screw 4 | ______ , ______ |
| Extra mounts (if any) | ______ |

Typical indoor P5 modules use **four corner magnets** about 8–12 mm in from each edge. Treat that only as a hint — drill from the measured centres.

---

## Housing dimensions (template)

Coordinate origin for the rear panel: **outer top-left**, Y down (same convention as the button-box faceplate).

| Item | Size (mm) |
|---|---|
| Outer W × H | **332 × 172** |
| Outer depth (front of walls to outside of rear) | **59** |
| Wall thickness | **6** (plywood / acrylic) |
| Inner pocket | **320 × 160** |
| Internal depth (front to inside of rear panel) | **56** |
| Rear panel | **332 × 172 × 3** |
| Cable cavity (behind connectors) | **28** |

Stack, front → back:

| Layer | Depth (mm) |
|---|---:|
| LED mask + PCB | 16 |
| HUB75 / ICs | 12 |
| Cable service loop | 28 |
| Rear panel | 3 |
| **Total** | **59** |

If your panel + sockets are thicker than 28 mm combined, add that extra to the side-wall depth so the **28 mm cavity** stays free.

---

## Cut list (6 mm plywood, 3 mm rear)

Butt joints: top and bottom run the full **332 mm** width; left and right sit between them so the inner height is **160 mm**.

| Part | Qty | Cut size (mm) | Material |
|---|----:|---|---|
| Top | 1 | **332 × 56** | 6 mm ply |
| Bottom | 1 | **332 × 56** | 6 mm ply |
| Left | 1 | **160 × 56** | 6 mm ply |
| Right | 1 | **160 × 56** | 6 mm ply |
| Rear panel | 1 | **332 × 172** | 3 mm ply / acrylic |
| Corner clips / magnet posts | 4 | see assembly | 3D-print, aluminium angle, or panel magnets |

Side-wall depth **56 mm** is the *internal* cavity (panel + sockets + cables). Glue the **3 mm** rear onto the back of those walls (overall depth 59 mm), or recess it 3 mm if you want a flush back.

**Acrylic / laser:** same outer sizes; 3 mm sides are too flexible at this span — use 5–6 mm or add a mid-span rib on the long edges.

**3D print:** 332 mm exceeds many beds. Print as four walls + rear, or split the shell on the vertical centreline with alignment pins.

---

## Rear panel — hole table (mm)

Outside view, looking at the back of the scoreboard. Cables drop **down** when the box is wall-hung.

| Feature | X | Y | Cut |
|---|--:|--:|-----|
| HUB75 ribbon slot (top-left of slot) | 122.0 | 128.0 | **28 × 10**, R2 corners |
| VH4 power grommet (centre) | 186.0 | 133.0 | **Ø12** |
| Vent left (centre) | 40.0 | 86.0 | Ø8 |
| Vent right (centre) | 292.0 | 86.0 | Ø8 |
| Cover screw 1 | 8.0 | 8.0 | Ø4.5 (M4 clear) |
| Cover screw 2 | 324.0 | 8.0 | Ø4.5 |
| Cover screw 3 | 8.0 | 164.0 | Ø4.5 |
| Cover screw 4 | 324.0 | 164.0 | Ø4.5 |
| Wall keyhole L (head centre) | 80.0 | 22.0 | Ø8 head, Ø4.5 neck, 10 mm drop |
| Wall keyhole R | 252.0 | 22.0 | same |

If HUB75 **IN** on your panel is far from the slot, keep the slot where it is and use the 28 mm cavity as slack — the included ribbon is ~30 cm. Do **not** put a tight 90° fold against the IDC strain relief.

Fit a rubber grommet in the Ø12 power hole so the VH4 jacket is not cut by the panel edge.

---

## How the panel is held

The 320 × 160 outline has **no extra flange**. Walls sit *beside* the panel, not in front of it.

1. Build the four-sided shell (no front skin).
2. From the **rear**, slide the panel in until the LED face is flush with the front of the walls.
3. Stop it from falling back with **one** of:
   - the panel’s own **magnetic posts** landing on steel discs glued to the inner rear face of the side walls / a thin internal keeper
   - four **M3/M4** posts through the panel’s corner holes into printed or wooden blocks
   - short aluminium-angle clips on the four inner corners, behind the PCB
4. Dress ribbon + power in the cavity, then fit the rear panel.

Do not sandwich the HUB75 sockets against the rear panel — leave the 28 mm loop.

---

## Assembly order

1. Cut and dry-fit the four walls. Inner opening must accept **320 × 160** with ~0.5 mm total clearance (aim **320.5 × 160.5** if the plywood is proud).
2. Glue / screw the shell square. Sand the front edges flush.
3. Cut the rear panel (use the SVG). Test-fit ribbon and power through the openings *before* mounting the matrix.
4. Fit retention clips or magnet landing pads.
5. Power **off**. Plug VH4 into the panel, route the pigtail through the grommet (leave ~80 mm slack inside).
6. Plug HUB75 **IN**, fold the ribbon once in the cavity, feed the free end through the slot.
7. Seat the panel flush, fit the rear panel with 4× M4.
8. Tie common **GND** with the Mega / PSU outside the box. Power the matrix from the **external 5 V** supply only.

Paint / stain after a dry assembly so finish does not bind the panel in the pocket.

---

## Materials (typical)

| Qty | Item |
|----:|---|
| — | 6 mm plywood or MDF for the shell |
| 1 | 3 mm plywood or acrylic for the rear panel |
| 4 | M4 × 16 mm screws + inserts (rear cover) |
| 1 | Ø12 mm rubber grommet (power) |
| 4 | Magnet landing discs or M3/M4 posts (panel retain) |
| — | Wood glue, 20 mm pins or pocket screws |
| optional | 2× wall screws for the keyholes |

---

## Notes

- **Ventilation:** the panel can draw up to ~20 W. Keep the two Ø8 vents; do not seal the ribbon slot.
- **No front bezel** over the LEDs — a 1 mm lip already eats edge pixels.
- Ribbon pin 1 (brown) still follows the [HUB75 colour matrix](hub75_ribbon_colour_matrix.png) once it reaches the Mega.
- This box does not replace strain relief at the Mega end — clamp the ribbon there as well.
- For a desk stand, skip the keyholes and add two rear feet so the cable exits stay clear of the table.

## Record (fill when built)

| Field | Value |
|---|---|
| Date | |
| Material / finish | |
| Measured panel thickness | |
| Magnet / screw pattern used | |
| Notes | |

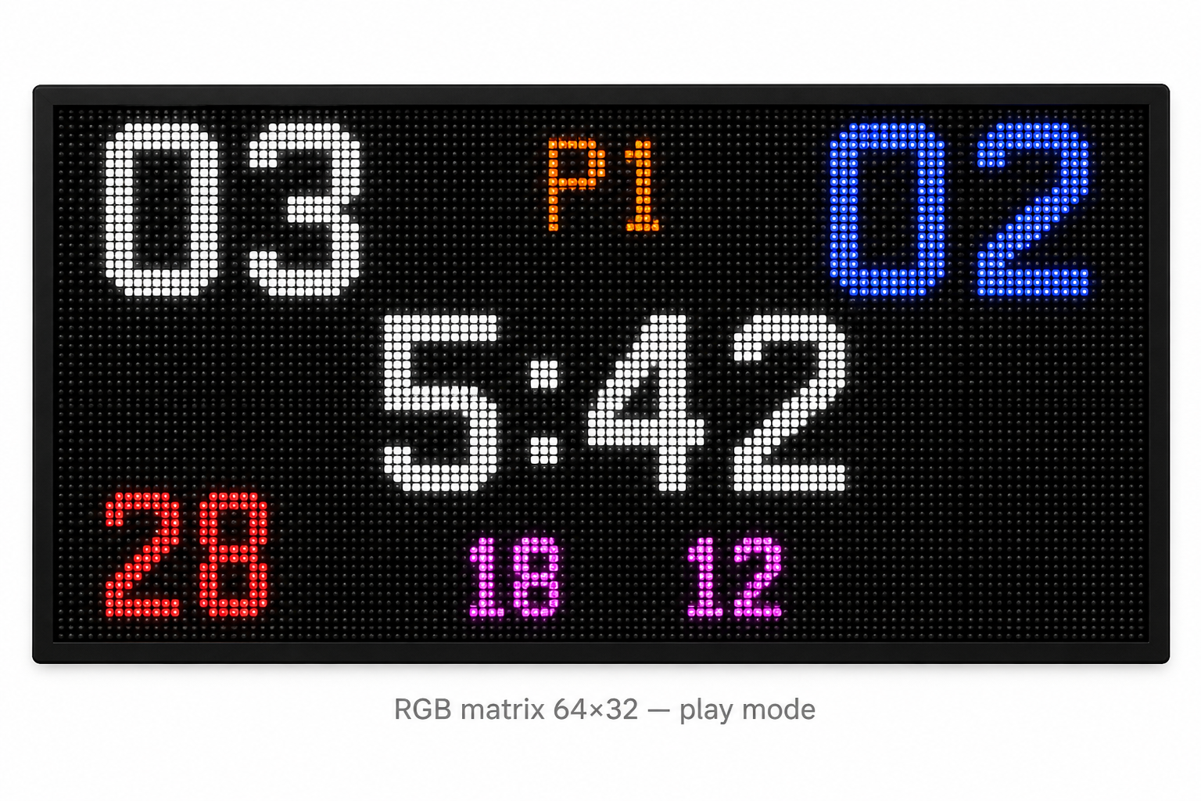
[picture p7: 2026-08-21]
docs/matrix_layout_play.png

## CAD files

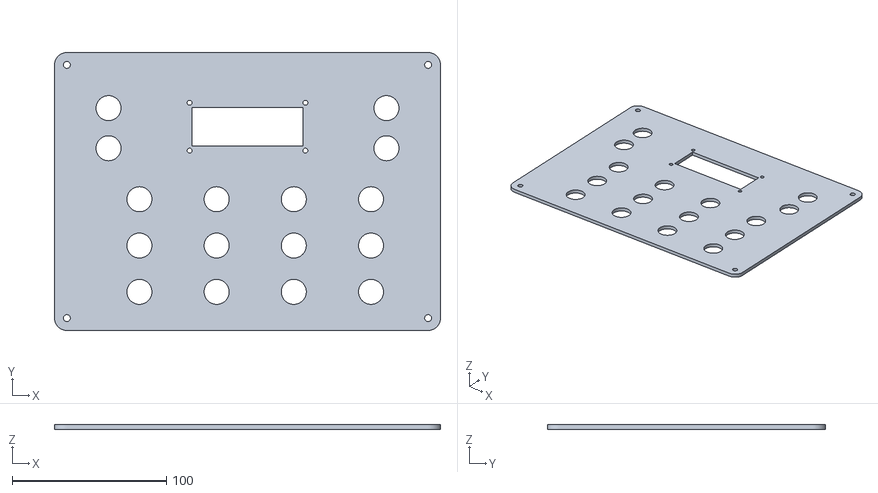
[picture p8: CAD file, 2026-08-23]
docs/button_box_panel_faceplate.stl
250.0 x 180.0 x 3.00

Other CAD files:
docs/button_box_panel_faceplate.obj

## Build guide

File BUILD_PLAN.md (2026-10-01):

# Build Plan: Water Polo Scoreboard (Arduino Mega)

Use this document as the **full specification and agent prompt** for building (or regenerating) the Water Polo Scoreboard project. Follow it end-to-end. If you tweak timing constants, pin numbers, or UI copy, keep behavior, file layout, and documentation structure the same so re-runs produce a similar project.

---

## Goal

Build an **operator scoreboard** for water polo on an **Arduino Mega 2560** that provides:

1. A **period clock** (default **6:30**)
2. **Home / Away** scores (0–99)
3. A **28-second shot clock** (with an 18 s partial reset)
4. **Timeout (1:00)** and **Interval (2:00)** modes
5. Two **18 s exclusion** timers
6. Local displays: **Waveshare 64×32 RGB HUB75 matrix** + **Freenove I2C 16×2 LCD**
7. A **5 V relay** horn/alarm on shot/period/TO expiry
8. **LoRa UART** broadcast of shot-clock values to remote shot clocks (`lora_remote` protocol)

---

## Required deliverables (must create all)

Create **all** of the following files. Do not stop after the sketch alone.

### 1. Main Arduino sketch (INO)

**Path (required):**

```text
waterpolo_scoreboard/waterpolo_scoreboard.ino
```

Arduino IDE requires the folder name to match the `.ino` basename.

### 2. Project README

**Path (required):**

```text
README.md
```

Contents must cover: parts list, feature summary / pin→action table, libraries, **full Mega pin map**, wiring diagrams (ASCII + references to `docs/` images if present), build & upload steps, first-run checks, display layouts, LoRa protocol notes, Freenove LCD notes, and a pointer to the hardware test sketch.

### 3. Operator usage guide

**Path (required):**

```text
USAGE.md
```

Write this as a **standalone operator guide** for someone running a game from the button box + LCD. Assume they do **not** need wiring or pin numbers — use panel labels (`START/STOP`, `+ HOME`, `28s RESET`, etc.). Include:

- What the LCD / matrix show
- Start/stop, scoring, shot clock, timeouts/intervals, exclusions
- Fine adjust (±1 / long ±10)
- Full game reset (combo hold)
- Typical period workflow
- Button quick-reference table

Also keep a condensed **How to use** section in `README.md` that either mirrors the guide or clearly links to `USAGE.md` (preferred: full operator content in `USAGE.md`, short summary + link in `README.md`).

### 4. Optional but recommended hardware smoke test

**Path:**

```text
test_d2_lcd/test_d2_lcd.ino
```

Minimal Mega sketch: D2 button (INPUT_PULLUP to GND) + Freenove I2C LCD on SDA/SCL (D20/D21). LCD shows `D2 + I2C LCD OK` and toggles `BTN: PRESSED` / `BTN: released` with a press counter.

### 5. Docs assets (if regenerating docs)

If regenerating documentation images, place under `docs/`:

- `docs/button_box_panel.png` — operator panel layout
- `docs/rgb_matrix_mega_wiring.png` — HUB75 → Mega wiring
- `docs/matrix_layout_play.png` — RGB matrix play-mode layout example

If images already exist, **reuse them** and reference them from README/USAGE. Do not delete them.

---

## Hardware (do not substitute without documenting)

| Qty | Part | Notes |
|----:|---|---|
| 1 | Arduino Mega 2560 | Required — Uno lacks pins |
| 1 | Waveshare RGB LED matrix 64×32 P3 | SKU **33840**, HUB75 |
| 1 | 5 V PSU for matrix | **≥ 2.5 A**, VH4 |
| 1 | Freenove I2C IIC LCD 1602 | I2C backpack onboard |
| 17 | Momentary push-buttons | Active LOW → GND, Mega INPUT_PULLUP |
| 1 | 5 V relay module | Driven by **D12** |
| 1 | LoRa UART module (TX) | e.g. DX-LR02 / DX-LR32 433 MHz |
| 1+ | LoRa remote shot clocks | Firmware `lora_remote/lora_remote.ino` |

**Power rules:**

- Matrix power from **external 5 V** on VH4 — never Mega 5 V.
- Common GND across PSU, Mega, matrix, LCD, LoRa, button commons.
- Configurable `RELAY_ACTIVE_HIGH` (default `true`).

---

## Libraries & board

Arduino Library Manager:

1. **Adafruit GFX Library**
2. **RGB matrix Panel** (Adafruit)
3. **LiquidCrystal I2C** (Frank de Brabander or Freenove zip)

**Board:** Arduino Mega or Mega 2560.

I2C LCD: try address **0x27**, fall back to **0x3F**.

---

## Exact pin map (must match)

### Buttons (INPUT_PULLUP, other side → GND)

| Pin | Function |
|----:|---|
| D2 | Period start/stop |
| D3 | Home + |
| D4 | Away + |
| D5 | Home − |
| D6 | Away − |
| D7 | Shot → 28 |
| D8 | Shot → 18 **if** current &lt; 18 |
| D36 | Period +1 s (long +10) |
| D37 | Period −1 s (long −10) |
| D38 | Shot +1 s (long +10) |
| D39 | Shot −1 s (long −10) |
| D40 | Timeout 1:00 |
| D41 | Interval 2:00 |
| D42 | Force shot → 18 (always) |
| D43 | RETURN — end TO/IN early |
| D47 | Exclusion 1 → 18 s |
| D48 | Exclusion 2 → 18 s |

### Outputs / buses

| Pin | Function |
|----:|---|
| D12 | Relay IN |
| D18 / D19 | Serial1 TX1 / RX1 → LoRa |
| D20 / D21 | I2C SDA / SCL → LCD |
| D9 / D10 / D11 | Matrix OE / LAT / CLK |
| D24–D29 | Matrix R1 G1 B1 R2 G2 B2 |
| A0–A3 | Matrix address A B C D |

**Do not use:** D0/D1 (USB serial), D22/D23 (matrix library PORTA).

Matrix constructor pattern:

```cpp
RGBmatrixPanel matrix(A, B, C, D, CLK, LAT, OE, true, 64);
```

---

## Timing & game constants

```text
PERIOD_SECONDS     = 6*60 + 30   // 6:30
SHOT_FULL          = 28
SHOT_PARTIAL       = 18
TIMEOUT_SECONDS    = 60
INTERVAL_SECONDS   = 2*60
EXCLUSION_SECONDS  = 18

DEBOUNCE_MS        = 15
LONG_PRESS_MS      = 5000        // D2 alone from stopped → period reset 6:30
ADJUST_LONG_MS     = 800         // D36–D39 long → ±10 s
COMBO_RESET_MS     = 5000        // D2 + D7 held → full reset

RELAY_SHOT_MS      = 500
RELAY_PERIOD_MS    = 1000
RELAY_TO_MS        = 500

LORA_BAUD          = 9600
LORA_RESEND_MS     = 500
LORA_DEFAULT_CHANNEL = 2         // 433.150 MHz
```

LoRa channel table CH0–3: `433.050 / .100 / .150 / .200` MHz (`AT+FREQ=` on Serial1).

---

## Behavioral specification (implement exactly)

### Modes

Define helpers (required — do not omit):

```cpp
bool inTimeout() { return timeoutLeft > 0; }
bool inInterval() { return intervalLeft > 0; }
bool inPlay()    { return !inTimeout() && !inInterval(); }
```

- **Play:** show period + shot (+ exclusions if active).
- **Timeout:** independent 1:00; period + shot **frozen**; exclusions pause.
- **Interval:** on start, load period **6:30** and shot **28**, clear exclusions; run independent 2:00.

### Period clock (D2)

- Short press in **play** only: toggle running (only start if `secondsLeft > 0`).
- While running: period and shot both count down each second.
- Shot clock runs **only** while period is running in play mode.
- Hold D2 ~5 s from a **stopped** press that did not also hold D7: reset period to 6:30 (do not start).
- During TO/IN, D2 does nothing — use RETURN first.

### Scoring

- Home+/Away+: score +1 (max 99); **stop** period; shot → 28.
- Home−/Away−: score −1 (min 0); clocks unchanged.

### Shot clock

- D7: shot → 28; period keeps running if it was.
- D8: shot → 18 only if `shotLeft < 18`.
- D42: shot → 18 always.
- At shot 0: pulse relay ~0.5 s; LoRa `0` then `BUZZER`; **stop both clocks**; reload shot to 28; send new value.

### Timeout / Interval / Return

- D40: `startTimeout()` — stop clocks, clear interval, set timeout 60.
- D41: `startInterval()` — stop clocks, clear timeout, reset period+shot+exclusions, set interval 120.
- D43: clear TO/IN immediately; after timeout keep shot value; after interval keep fresh 6:30/28.
- When TO or IN hits 0: short relay pulse; return to play display (clocks stopped).

### Exclusions (D47 / D48)

- Start only when that slot is **0** (cannot restart while &gt; 0).
- Set slot to 18; **pause** period clock; apply D8 rule if shot &lt; 18.
- Tick only while period clock is running in play; pause in TO/IN and when stopped.

### Fine adjust (D36–D39)

- Short release: ±1 s; long hold (~0.8 s): ±10 s.
- Do **not** start/stop clocks.
- Period adjust only in play; clamp 0…PERIOD_SECONDS; if period hits 0, stop clock.
- Shot adjust clamp 0…28; send to LoRa on change.

### Full reset

Hold **D2 + D7** together for **5 s**:

- Scores 0–0, period 6:30, shot 28, clear TO/IN/exclusions, clocks stopped.
- Suppress leftover D2 long-press period reset.
- While combo is forming, do not toggle clock / do not apply D7 shot reset.

### Period expiry

When period hits 0: stop clock; relay ~1 s; LoRa `END`.

### Defaults at boot / full reset

Scores **0–0**, period **6:30**, shot **28**, clocks **stopped**.

---

## Software architecture (sketch structure)

Implement in a **single** `.ino` with clear sections:

1. Includes + pin constants + `RELAY_ACTIVE_HIGH`
2. Matrix + LCD init (I2C address probe)
3. LoRa helpers (`forwardToLoRa`, `setLoRaChannel`, `sendShotToLoRa`)
4. Scoreboard state variables
5. Debounced button table (`Btn` struct, 15 ms debounce)
6. Relay pulse service (`relayOffAtMs`)
7. Mode helpers `inTimeout` / `inInterval` / `inPlay`
8. `setShotClock`, `onShotExpired`, `startTimeout`, `startInterval`, `startExclusion`, `fullResetToDefaults`
9. `setup()` / `loop()`
10. `pollButtons` / `onButtonPress` / `onButtonRelease` / long-press + combo services
11. `updateClocks` (1-second tick accumulation via `lastTickMs`)
12. `drawLcd` / `drawMatrix` / `drawAll` / `markDirty`

### `loop()` responsibilities

- Poll buttons frequently (multiple times per loop is fine).
- Update clocks / relay.
- While play + running: re-broadcast shot value to LoRa every **0.5 s**.
- Redraw matrix when dirty, or ~200 ms when blinking at zero.

### Display layouts

**LCD play:**

```text
H:03 A:02 SC:28
5:42* X18/12
```

**LCD TO / IN:**

```text
H:03 A:02 SC:28
TO 0:45
```

```text
H:03 A:02 SC:28
IN 1:30
```

(`*` when period running; exclusion `Xaa/bb` only when at least one active.)

**Matrix play:**

```text
03      P1      02
      5:42
28     e1 e2
```

Timeout / interval / half-time: top centre becomes `TO` / `IN` / `HT`; large middle clock shows the break time. On **TO**, frozen period clock is copied bottom-right next to the shot.

Colors (Color333 / bitbang equivalents):

- Home white, Away medium blue (scores only — no H/A labels)
- Labels (`P#` / `TO` / `IN` / `HT`) orange
- Main clock: white &gt;1:00, orange ≤1:00 down to 0:29, red ≤0:28 (blink at 0:00)
- Shot always red
- Exclusions magenta; only while &gt; 0 (play mode)

Always clear then draw (bitbang `clear` / Adafruit `fillScreen(0)` + `swapBuffers` when double-buffered).

---

## LoRa protocol (compatible with `lora_remote`)

| Item | Value |
|---|---|
| Link | Serial1 @ 9600 |
| Framing | Newline-terminated text |
| Shot value | Decimal string `28`, `18`, `0`, … |
| Shot expired | `0` then `BUZZER`, then master stops + reloads 28 |
| Period expired | `END` |
| While running | Resend current shot every 0.5 s |
| Channel set | `AT+FREQ=<hz>` at boot for default channel |

---

## README.md outline (required sections)

Write `README.md` with at least these sections, in roughly this order:

1. Title + one-paragraph product summary
2. Parts list (table)
3. What it does (control / pin / action table)
4. Short pointer to **USAGE.md** for operators
5. Libraries + board + I2C addresses
6. Full Arduino Mega pin map (digital + analog, USED / RESERVED / SPARE / AVOID)
7. Wiring diagram (panel layout, HUB75 table, ASCII system overview, relay notes, power rules)
8. Build & upload instructions + first-run checks table
9. Displays (LCD + matrix examples)
10. LoRa protocol
11. Freenove I2C LCD notes
12. Quick hardware test (`test_d2_lcd`)

Include operator panel layout table mapping faceplate positions to pins (as in the current project).

Reference existing images if present:

```markdown
![Operator control panel button layout](docs/button_box_panel.png)
![RGB Matrix HUB75 wiring to Arduino Mega](docs/rgb_matrix_mega_wiring.png)
```

---

## USAGE.md outline (required sections)

Write `USAGE.md` as the operator-facing guide:

1. Title + intro (button box + LCD; no wiring needed)
2. Panel layout image reference (if available)
3. What you see (LCD / matrix table)
4. Start / stop the period
5. Scoring
6. Shot clock
7. Timeouts and intervals
8. Exclusions
9. Fine adjust
10. Full game reset
11. Typical period workflow (numbered steps)
12. Button quick reference table (panel labels only)

Mirror the behavioral rules from this plan; keep language non-technical.

---

## Suggested operator panel layout (document + wire)

| Position | Control | Pin |
|---|---|-----|
| Top left | Home + / − | D3 / D5 |
| Top right | Away + / − | D4 / D6 |
| Mid left of LCD | Timeout 1:00 | D40 |
| Center | I2C LCD | SDA20 / SCL21 |
| Mid right of LCD | Interval 2:00 · Return | D41 · D43 |
| Under LCD left | Period ±1 s | D36 / D37 |
| Under LCD right | Shot ±1 s | D38 / D39 |
| Bottom L→R | 28 · 18 · Excl1 · Excl2 · Force18 · Start/Stop | D7 · D8 · D47 · D48 · D42 · D2 |

---

## Implementation order (agent checklist)

Execute in this order:

1. **Create folder** `waterpolo_scoreboard/` and write `waterpolo_scoreboard.ino` implementing the full behavioral spec above (including `inPlay` / `inTimeout` / `inInterval`).
2. **Create** `USAGE.md` (operator guide).
3. **Create/update** `README.md` (hardware + wiring + build + link to USAGE).
4. **Create** `test_d2_lcd/test_d2_lcd.ino` smoke test.
5. Keep or reference `docs/*.png` wiring/panel images.
6. Preserve `LICENSE` / `.gitignore` if present; do not invent unrelated apps.
7. Sanity-check the sketch for:
   - All 17 buttons present and mapped
   - Mode helpers defined
   - Combo reset D2+D7
   - LoRa resend while running
   - Relay pulses on shot / period / TO-IN end
   - LCD + matrix layouts match the examples
8. Commit with a clear message describing the scoreboard deliverables.

---

## Non-goals / out of scope

- LoRa remote firmware lives in `lora_remote/` (see `docs/lora_remote_build.md`). Do not fold it into the Mega sketch.
- Do **not** target Arduino Uno / Nano (insufficient pins / wrong PORTA mapping).
- Do **not** drive the matrix from Mega 5 V.
- Do **not** replace HUB75 data pins 24–29 (Adafruit Mega requirement).
- Do **not** omit documentation: INO + README + USAGE are all mandatory.

---

## Acceptance criteria

The build is complete when:

- [ ] `waterpolo_scoreboard/waterpolo_scoreboard.ino` exists and compiles conceptually for Mega 2560 with the three libraries listed
- [ ] All pins, timings, and button behaviors match this plan
- [ ] `README.md` documents parts, pins, wiring, upload, LoRa, displays
- [ ] `USAGE.md` is a standalone operator guide
- [ ] `test_d2_lcd/test_d2_lcd.ino` exists for LCD+D2 bring-up
- [ ] First-run expectations match: LCD `H:00 A:00 SC:28` / `TIME 6:30` (or equivalent period line), matrix HOME/AWAY 00 with `6:30` and `28`

---

## How to re-run / tweak

When re-running an agent against this plan:

1. Paste or attach **this entire `BUILD_PLAN.md`**.
2. State any deltas explicitly at the top, e.g. “Change period to 8:00” or “Add a third exclusion on D49”.
3. Instruct: **Create/overwrite the INO, README.md, and USAGE.md per the plan; preserve docs images unless regenerating.**
4. Expect a similar file tree and behavior; only planned deltas should change.

Example follow-up prompt:

```text
Follow BUILD_PLAN.md exactly.
Tweaks: PERIOD_SECONDS = 8:00; keep everything else identical.
Create waterpolo_scoreboard/waterpolo_scoreboard.ino, README.md, and USAGE.md.
```

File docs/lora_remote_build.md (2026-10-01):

# LoRa remote shot clock — wiring

One remote shows the shot clock sent by the Mega scoreboard. The sketch is `lora_remote/lora_remote.ino` (pins in `lora_remote/scoreboard_commands.h`). This guide is the wiring only: no case, no PCB.

The master and this remote must use the same LoRa settings. Both sketches default to **channel 2 = 433.150 MHz**, spreading factor **7**, power **22 dBm**.

---

## Shopping list (one remote)

Prices change. Links are the Amazon UK pages for these parts.

| Qty | Part | Use | Link |
| --- | --- | --- | --- |
| 1 | Arduino Nano Every **with headers** (ABX00033) | Controller | [B07WWK29XF](https://www.amazon.co.uk/dp/B07WWK29XF) |
| 2 | PATIKIL 4 inch common-anode digit, red, 7.2 V, 10 pin (FJS40101DH) | Tens digit and ones digit. The listing is **one** digit | [B0C5MSYB28](https://www.amazon.co.uk/dp/B0C5MSYB28) |
| 1 | DX-LR32 UART LoRa module + antenna, from the 2-pack | Radio. The second module in the pack can go on the Mega master | [B0GV3KN1HC](https://www.amazon.co.uk/dp/B0GV3KN1HC) |
| 1 | 12 V mini siren, 120 dB | Horn. The sketch pulses it; it is not a 5 V buzzer | [B07CV7SHYL](https://www.amazon.co.uk/dp/B07CV7SHYL) |
| 1 | Round SPST rocker, from the 10-pack | Power switch in the battery positive lead | [B07ZTJNRXT](https://www.amazon.co.uk/dp/B07ZTJNRXT) |
| 2 | LM2596 buck modules, from the 10-pack | One set to **5.0 V** (Nano + LoRa). One set to **9.0 V** (digit anodes) | [B0B5GQTS64](https://www.amazon.co.uk/dp/B0B5GQTS64) |
| 1 | 12 V 6800 mAh rechargeable pack, DC 5.5×2.1 mm, with its charger | Power. Blue pack in the parts photo | [B00BWW9WRM](https://www.amazon.co.uk/dp/B00BWW9WRM) |
| 16 | 150 Ω resistors, ¼ W | One in each segment and decimal-point lead | — |
| 1 | Small NPN (2N2222 or similar) and a 1 kΩ resistor | Switches the 12 V siren from Nano **D10** | — |
| 1 | 1N4007 diode | Across the siren | — |

Also: USB lead for the Nano Every (USB micro), hook-up wire, and a multimeter. The buck modules leave the factory near full input voltage. **Measure and set them before they touch the Nano or the digits.**

The linked LoRa size is **DX-LR32-900T22D**. The listing text says the DX-LR32 series can be set from 433 MHz through 930 MHz. This sketch sends `AT+FREQ=433150000`. After upload, Serial Monitor must show that command with no error from the module. If the module rejects 433 MHz, it will not hear a master that is on channel 2.

---

## Power

```text
Battery +  -- rocker --+-- LM2596 #1 IN+
Battery −  ------------+-- LM2596 #1 IN−
                        |
                        +-- LM2596 #2 IN+
                        +-- LM2596 #2 IN−   (same battery −)

LM2596 #1 OUT+  = 5.0 V  -->  Nano 5V,  LoRa VCC
LM2596 #1 OUT−  = GND    -->  Nano GND, LoRa GND

LM2596 #2 OUT+  = 9.0 V  -->  digit common anodes only (pins 1 and 8)
LM2596 #2 OUT−  = GND    -->  Nano GND
```

1. Turn the **battery pack switch** on. The rocker is a second switch in the positive lead, so the remote can be switched off without opening the pack.
2. With the Nano **unplugged**, set buck 1 to **5.0 V** and buck 2 to **9.0 V**.
3. Program the Nano from USB with the **rocker off**, so USB 5 V and the buck are not both feeding the board. Run the remote from the battery with the USB lead **unplugged**.
4. Do not connect the 9 V rail, or the raw 12 V battery, to any Nano pin.

The digits drop about **7.2 V** at full brightness. The 9 V rail plus **150 Ω** in each cathode lead is about **12 mA** per segment: `(9.0 − 7.2) / 150`. Do not use a lower resistor. A review of this digit reports segments failing when held near 18 mA. The Nano sinks that current directly (the sketch has no segment-driver chip), so two digits showing `8` is a lot of pin current. Leave the resistors at 150 Ω.

---

## Digits

Both modules are **common anode**. Pins **1 and 8** are the commons. Tie pin 1 and pin 8 on each digit to the **9 V** buck. Do not tie the two digits' segment pins together.

The sketch lights a segment by driving that Nano pin **LOW**. A **HIGH** pin is off.

| Segment | Ones digit (right) | Tens digit (left) |
| --- | --- | --- |
| A | D8 | A6 |
| B | D7 | A5 |
| C | D6 | A4 |
| D | D5 | A3 |
| E | D4 | A2 |
| F | D3 | A1 |
| G | D2 | A0 |
| DP | D9 | A7 |

Put the **150 Ω** resistor in the wire from the digit pin to the Nano pin. Either end of that wire is fine.

The listing names the commons and not the segment letters. Before soldering all sixteen wires, check one cathode at a time: 9 V on pins 1 and 8, 150 Ω from a cathode pin to GND. Note which bar lights, then connect that letter to the pin in the table. Decimal points stay wired; the sketch holds them off except for a `TEST` command.

Numbers **1–9** leave the tens digit blank. **10–28** use both digits. A shot value of **0** clears the display (the horn is a separate `BUZZER` message from the master).

---

## Horn

D10 goes **HIGH** for about half a second on `BUZZER`, and for about one second on `END`. The siren is a **12 V** load. Do not connect it to D10 and GND.

```text
Switched 12 V ----+---- siren red (+)
                  |
               1N4007 cathode
                  |
Siren black (−) --+---- NPN collector
                       NPN emitter ---- GND
Nano D10 -- 1 kΩ -- NPN base
```

Diode band (cathode) toward the 12 V side, across the siren. Any small NPN such as a 2N2222 is enough for the short pulses this sketch sends.

---

## LoRa module

Nano Every **Serial** is the USB port (debug, 9600). **Serial1** is the radio, also 9600:

| DX-LR32 | Nano Every |
| --- | --- |
| VCC | 5 V (buck 1) |
| GND | GND |
| TXD | D0 (RX) |
| RXD | D1 (TX) |

TX and RX cross. Leave AUX unconnected. Fit the antenna before you power the module.

`LORA_DEFAULT_CHANNEL` in `lora_remote.ino` must match the master. Default on both is **2**.

| Channel | Frequency |
| --- | --- |
| 0 | 433.050 MHz |
| 1 | 433.100 MHz |
| 2 | 433.150 MHz |
| 3 | 433.200 MHz |

---

## Upload

1. Arduino IDE, board **Arduino Nano Every**, sketch `lora_remote/lora_remote.ino`.
2. Rocker **off**. Upload over USB.
3. Open Serial Monitor at **9600**. You should see `LoRa remote scoreboard ready`, then `AT+FREQ=433150000`, `AT+SF7`, and `AT+POWE22`.
4. Unplug USB, turn the rocker on, and start the master shot clock. The digits should follow the shot time. At **0** the digits clear and the siren pulses.

The sketch does not wait for the USB port, so it will start on the battery with no computer attached.

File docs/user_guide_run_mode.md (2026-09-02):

# User guide — RUN mode (running clock)

Use this guide when the timing menu **CLOCK** page is set to **RUN** or **RUN-NS**.

In **RUN** mode the **period** can keep counting while the **shot** clock is stopped (for goals, exclusions, shot expiry, etc.). Exclusions start and stop with the **shot** clock — same as pressing **START/STOP** for play.

**RUN-NS** uses the same period / **START/STOP** rules as **RUN**, but the shot clock is fully off (hidden on displays, blanked on LoRa remotes, shot buttons ignored). Exclusions count down with the **period** clock; the LCD `*` shows while the period is running.

Related guides:

- [Timing menu](user_guide_timing_menu.md)
- [STOP mode button guide](user_guide_stop_mode.md)

Also summarised in the main [README — How to use](../README.md#how-to-use).

---

## Core idea

| Concept | Behaviour |
|---|---|
| **Period running** | Main game clock is counting down. |
| **Play running** | Shot + exclusions are counting (LCD `*` on). In **RUN-NS**, shot is disabled — `*` means the period is running. |
| **Exclusions (RUN)** | Start/stop with **shot/play** (short **START/STOP**). Pause during TO/IN/HT. |
| **Exclusions (RUN-NS)** | Count down with the **period** clock. Pause during TO/IN/HT. |
| After first start of a quarter | Short **START/STOP** only toggles **play**. Period keeps going. |
| To stop the period | **Long-press START/STOP** (~3 s), or call **TIMEOUT** / **INTERVAL**, or wait for 0:00. |

Timeout still **stops the period**. After **RETURN** from timeout, press **START/STOP** to start period + play again.

---

## START/STOP

| Situation | Short press | Hold ~3 s |
|---|---|---|
| Period **not** running (new quarter, or after timeout) | Starts **period + play** together | — (no period to stop) |
| Period running, **play running** | Stops **play** only (period keeps running) | Stops **period + play** |
| Period running, **play stopped** | Release starts **play** (press alone waits so a long hold can stop the period) | Stops **period** (and play stays stopped) |
| During **TIMEOUT** or **INTERVAL / HT** | No effect — use **RETURN** first | — |

### Typical flow each quarter

1. Short **START/STOP** → period and shot start.
2. Goal / exclusion / shot expiry → shot/play stops; **period keeps running** (exclusions pause in **RUN**, keep counting in **RUN-NS** except goals clear them).
3. Short **START/STOP** → shot and exclusions resume (**RUN**); period still running.
4. To freeze the whole quarter early → hold **START/STOP** ~3 s.

---

## Combos involving START/STOP

| Hold | Time | Effect |
|---|---|---|
| **START/STOP** + **28s RESET** | ~**3 s** | **Full reset** (same as STOP mode): scores, clocks, exclusions, timing defaults, **CLOCK → STOP**. |
| **START/STOP** + **RETURN** | ~**3 s** | Reload period to match length; **keep** current shot and exclusion values; **stops** period + play. |

---

## Scoring

| Button | Period (RUN) | Play / shot / exclusions |
|---|---|---|
| **+ HOME** / **+ AWAY** | **Keeps running** | Score +1. Shot → **28**. Clear exclusions. **Play stops** until **START/STOP**. |
| **− HOME** / **− AWAY** | Unchanged | Score −1 only. |

---

## Shot clock

Applies when **CLOCK = RUN**. In **RUN-NS** the shot clock is disabled — skip this section.

| Button / event | Period (RUN) | Play / shot |
|---|---|---|
| **28s RESET** | Unchanged | Shot → **28**; clear exclusions; **run state unchanged** (play stays running or stopped). |
| **18s RESET** | Unchanged | Shot → **18** only if &lt; 18; run state unchanged. |
| **FORCE 18** | **Keeps running** | Shot → **18**; **play stops**. |
| Shot reaches **0** | **Keeps running** | Horn + LoRa `BUZZER`; shot → **28**; **play stops**. |

When period remaining is less than the shot value **and the period is running**, the shot display follows the period seconds.

---

## Exclusions

| Button | Period | Exclusions |
|---|---|---|
| **EXCL** (1st / 2nd press) | **Keeps running** | Arm clock 1 then 2 (**18 s**). If shot &lt; 18 (and **CLOCK = RUN**), apply 18s rule. **Shot/play stops** — exclusions **pause** in **RUN** (resume with **START/STOP**); in **RUN-NS** they **keep counting** with the period. |

Same slot rules as STOP mode: cannot restart an active clock; remaining time kept across IN/HT; goal or **28s RESET** clears both.

Press **START/STOP** to resume shot/play in **RUN** (period is usually still running). In **RUN-NS**, exclusions need no button — they follow the period.

---

## Timeout and interval

Same break behaviour as STOP mode — these **do** stop the period:

| Button | Effect |
|---|---|
| **TIMEOUT** | Stops **period + play**. Independent `TO` countdown. |
| **INTERVAL** | Stops **period + play**. Advances period; loads match length + shot 28; keeps exclusions; runs **IN** or **HT**. |
| Period hits **0:00** | Horn; LoRa `END`; auto **IN/HT** on P1–P3. |

| **RETURN** | Effect |
|---|---|
| **Short press** during TO/IN/HT | End break early (silent). |
| **Hold ~3 s** during TO/IN/HT | End break + buzzer. |
| **Hold ~3 s** in play | Buzzer only. |
| Short press in play | No effect. |

After timeout or break, the period is **stopped** until you short-press **START/STOP** (starts period + play again).

---

## Time adjust

Same controls as STOP mode:

| Button | Short | Long (~0.8 s) |
|---|---|---|
| **GAME +1s / −1s** | Period ±1 s | +10 / −30 s |
| **SHOT +1s / −1s** | Shot ±1 s (ignored in **RUN-NS**) | ±10 s |

Period adjust only in play display (not during TO/IN). Adjusting period to **0:00** stops period + play.

Pre-first-START period edits still update match length for later quarters.

---

## Timing menu access

| Hold | Time | Effect |
|---|---|---|
| **18s RESET** + **28s RESET** | ~**3 s** | Open timing menu. Stops period + play. See [Timing menu guide](user_guide_timing_menu.md). |

---

## STOP vs RUN — quick comparison

| Event | STOP mode | RUN mode |
|---|---|---|
| Short **START/STOP** | Toggle period + play | First start: both. Later: play only |
| Long **START/STOP** (~3 s) | From stopped: reload period | Stop period (+ play) |
| Goal / EXCL / FORCE 18 / shot = 0 | Stop period + play | Period keeps; play stops |
| **TIMEOUT** | Stop period + play | Stop period + play |
| **28s / 18s RESET** | Do not toggle run state | Same |

---

## Quick reference — RUN mode

| Control | Short | Long / hold | Combo |
|---|---|---|---|
| **START/STOP** | Start period+play, or toggle play only | ~3 s → stop period | +**28s** full reset; +**RETURN** period reload keep shot/excl |
| **+ HOME / + AWAY** | Goal; play stops; period keeps; shot 28 (ignored in **RUN-NS**); clear excl | — | — |
| **− HOME / − AWAY** | Score −1 | — | — |
| **28s RESET** | Shot 28; clear excl; run state kept | — | with **18s** → menu; with **S/S** → full reset |
| **18s RESET** | Shot → 18 if &lt; 18 | — | with **28s** → menu |
| **FORCE 18** | Shot 18; play stops; period keeps | — | — |
| **EXCL** | Arm excl; play stops; period keeps | — | — |
| **TIMEOUT** | Start TO (stops period) | — | — |
| **INTERVAL** | Next period + IN/HT | — | — |
| **RETURN** | End TO/IN silent | ~3 s buzzer (+ end TO/IN) | with **S/S** → period reload |
| **GAME ±** | ±1 s period | +10 / −30 s | — |
| **SHOT ±** | ±1 s shot | ±10 s | — |

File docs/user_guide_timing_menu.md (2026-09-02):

# User guide — Timing menu

How to open the timing menu and what each page does. Values are kept in memory until a **full reset** (they are not stored when power is removed).

Related guides:

- [Buttons in STOP (Start/Stop) mode](user_guide_stop_mode.md)
- [Buttons in RUN mode](user_guide_run_mode.md)

Also summarised in the main [README — How to use](../README.md#how-to-use).

---

## Open and leave the menu

| Action | Result |
|---|---|
| Hold **18s RESET** + **28s RESET** together ~**3 s** | Opens the timing menu. All clocks stop. |
| **START/STOP** (shown as **S/S** on the LCD) | Next page. On the last page (**CLOCK**), confirms and **exits**. |
| **RETURN** | Exit immediately (keeps changes already made). |
| Any other button | Ignored while the menu is open. |

LCD example:

```text
SET PERIOD  1/7
8:00  S/S next *
```

Shot-clock pages show seconds (e.g. `28s`) instead of `m:ss`. Last page shows `S/S OK` instead of `S/S next`. The `*` is a brief command-ack flash.

---

## Menu pages (1 → 7)

| # | Page | Default | Range | Adjust with **GAME +1s / −1s** |
|---|---|---|---|---|
| 1/7 | **PERIOD** | 8:00 | 0:30–15:00 | ±**30 s** per press |
| 2/7 | **INTERVAL** | 2:00 | 0:00–3:00 | ±**30 s** |
| 3/7 | **HALFTIME** | 2:00 | 0:00–7:00 | ±**30 s** |
| 4/7 | **TIMEOUT** | 1:00 | 0:30–5:00 | ±**30 s** |
| 5/7 | **SHOT 28** | 28 s | 1–60 s | ±**1 s** |
| 6/7 | **SHOT 18** | 18 s | 1–60 s | ±**1 s** |
| 7/7 | **CLOCK** | **STOP** | STOP, RUN, or RUN-NS | Cycle **STOP → RUN → RUN-NS** (no time step) |

Long-press on **GAME +1s / −1s** is not used in the menu — each press steps once (±30 s, ±1 s on shot pages, or cycles CLOCK).

---

## What each option means

### PERIOD

Match length for each quarter (P1–P4). Used when:

- You press **INTERVAL** (loads the new period)
- You reload the period (mode-specific — see STOP / RUN guides)
- Full reset restores the factory default (**8:00**)

If the current period has **not** been started yet, changing **PERIOD** also updates the live period clock on the displays.

### INTERVAL

Break length between periods when the break is labelled **IN** (after P1 and after P3). After P2 the board uses **HALFTIME** instead.

### HALFTIME

Break length after **P2** (display label **HT**). Official half-time is often 5:00; the default in firmware is currently **2:00** — set it here for your competition.

### TIMEOUT

Length of a team timeout when you press **TIMEOUT** (display label **TO**).

### SHOT 28

Length loaded by **28s RESET**, a goal (**+ HOME** / **+ AWAY**), **INTERVAL**, and shot-clock expiry. Live shot **+1s / −1s** also cannot go above this value.

If the live shot is already at the old **SHOT 28** length (or longer than the new value), changing this page updates the live shot clock to match.

### SHOT 18

Length loaded by **18s RESET** (only if the current shot is **shorter** than this value) and **FORCE 18**. **EXCL** uses the same rule when the shot is shorter than this value.

### CLOCK

Chooses how **START/STOP** behaves during play:

| Setting | Meaning |
|---|---|
| **STOP** (default) | Start/Stop mode: period, shot, and exclusions start and stop together. |
| **RUN** | Running-clock mode: after the period is live, short **START/STOP** only starts/stops shot + exclusions; the period keeps counting until you stop it with a long press (or timeout / interval / period end). |
| **RUN-NS** | Same period behaviour as **RUN**, but the shot clock is **disabled**: hidden on the LCD/matrix, blanked on LoRa remotes, and shot buttons are ignored. Exclusions count down with the **period** clock. |

Full button guides:

- [STOP mode](user_guide_stop_mode.md)
- [RUN mode](user_guide_run_mode.md) (covers **RUN** and **RUN-NS**)

---

## Typical setup before a game

1. Hold **18s RESET** + **28s RESET** ~3 s.
2. Set **PERIOD** (e.g. 8:00 or 6:30).
3. Press **S/S** → set **INTERVAL**.
4. Press **S/S** → set **HALFTIME**.
5. Press **S/S** → set **TIMEOUT**.
6. Press **S/S** → set **SHOT 28** (e.g. 28 or 30).
7. Press **S/S** → set **SHOT 18** (e.g. 18 or 20).
8. Press **S/S** → set **CLOCK** to **STOP**, **RUN**, or **RUN-NS**.
9. Press **S/S** (**OK**) to leave, or press **RETURN** at any time.

---

## Notes

- Opening the menu **stops** the period and play clocks.
- Leaving the menu does **not** auto-start play — press **START/STOP** when ready.
- A **full reset** (hold **START/STOP** + **28s RESET** ~3 s) restores all timing values and sets **CLOCK** back to **STOP**.

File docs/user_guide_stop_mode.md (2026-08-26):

# User guide — STOP mode (Start/Stop clock)

Use this guide when the timing menu **CLOCK** page is set to **STOP** (the default).

In STOP mode, **period**, **shot**, and **exclusion** clocks start and stop **together**.

Related guides:

- [Timing menu](user_guide_timing_menu.md)
- [RUN mode button guide](user_guide_run_mode.md)

Also summarised in the main [README — How to use](../README.md#how-to-use).

---

## Core idea

| Concept | Behaviour |
|---|---|
| **Play** | Period + shot + exclusions are all running, or all stopped. |
| **START/STOP** | Toggles that whole group on/off. |
| **Timeout / interval** | Period and shot freeze; independent TO or IN/HT countdown runs. |

LCD `*` next to the shot value means play is running.

---

## START/STOP

| Press | Effect |
|---|---|
| **Short press** (play mode only) | Toggle period + shot + exclusions together. First start of a quarter marks the period as started. |
| **Hold ~3 s** (clocks **stopped**) | Reload period clock to the current match length (`PERIOD`). May also pull the shot clock down if it is longer than the new period. Does **not** start the clocks. |
| During **TIMEOUT** or **INTERVAL / HT** | No effect — use **RETURN** (or wait for the break to end). |

---

## Combos involving START/STOP

| Hold | Time | Effect |
|---|---|---|
| **START/STOP** + **28s RESET** | ~**3 s** | **Full reset**: scores 0–0, P1, period 8:00, shot 28, clear TO/IN/HT/exclusions, clocks stopped, timing menu values → defaults, **CLOCK → STOP**. |
| **START/STOP** + **RETURN** | ~**3 s** | Reload period to match length; **keep** current shot and exclusion values; clocks stop. |

---

## Scoring

| Button | Effect |
|---|---|
| **+ HOME** / **+ AWAY** | Score +1 (max 99). **Stops** period + shot + exclusions. Shot → **28**. Clears both exclusion clocks. |
| **− HOME** / **− AWAY** | Score −1 (min 0). Clocks unchanged. |

After a goal, press **START/STOP** when play resumes.

---

## Shot clock

| Button | Effect |
|---|---|
| **28s RESET** | Shot → **28**. Period run state unchanged. **Clears** both exclusion clocks. |
| **18s RESET** | Shot → **18** only if current value is **&lt; 18**. Period run state unchanged. |
| **FORCE 18** | Shot → **18** always. **Stops** period + shot + exclusions. |
| Shot reaches **0** | Horn/relay (~0.5 s); LoRa `BUZZER`; **stops** all clocks; shot reloads to **28**. |

When period remaining is less than the shot value, the shot display follows the period seconds.

---

## Exclusions

| Button | Effect |
|---|---|
| **EXCL** (1st press) | Start exclusion clock 1 (**18 s**). **Stops** period + shot + exclusions from running. If shot &lt; 18, applies the 18s rule. |
| **EXCL** (2nd press) | Start exclusion clock 2 (same rules) while clock 1 is still active. |
| Both clocks busy | Further presses do nothing. |

Notes:

- A slot only arms from **0**; you cannot restart an active clock until it reaches 0.
- Exclusion timers tick only while play is running; they pause when play is stopped and during TO/IN.
- Remaining exclusion time is **kept** across **INTERVAL / HT** into the next period.
- A **goal** or **28s RESET** clears both clocks.

Press **START/STOP** to resume play (and continue any active exclusion countdown).

---

## Timeout and interval

| Button | Effect |
|---|---|
| **TIMEOUT** | Stops period + play. Runs independent timeout countdown (`TO`). Length from menu **TIMEOUT**. |
| **INTERVAL** | Stops period + play. Advances period (P1→P4). Loads match period length + shot **28**. Keeps remaining exclusions. Runs **IN** or **HT** (HT after leaving P2). |
| Period hits **0:00** | Horn (~1 s); LoRa `END`. On P1–P3 auto-starts **IN/HT** (same as **INTERVAL**). On P4 stays at 0:00. |

| **RETURN** | Effect |
|---|---|
| **Short press** during TO/IN/HT | End break early (silent). Back to period + shot display. |
| **Hold ~3 s** during TO/IN/HT | End break **and** sound buzzer (relay + LoRa). |
| **Hold ~3 s** in play (not in TO/IN) | Buzzer only. |
| Short press in play | No effect. |

After timeout: shot value is **kept**; press **START/STOP** to resume.  
After interval / HT: fresh period at match length / shot 28; exclusions kept; press **START/STOP** to start.

---

## Time adjust (play mode only for period)

| Button | Short press | Long press (~0.8 s) |
|---|---|---|
| **GAME +1s** | Period +1 s | Period +**10 s** |
| **GAME −1s** | Period −1 s | Period −**30 s** |
| **SHOT +1s** | Shot +1 s | Shot +**10 s** |
| **SHOT −1s** | Shot −1 s | Shot −**10 s** |

Limits: period **0:00–15:00** (live), shot **0–28**. Period adjust does nothing during TO/IN. If period is set to **0:00**, clocks stop.

If you change the period clock **before the first START** of the current period, that value becomes the **match length** for later periods.

---

## Timing menu access

| Hold | Time | Effect |
|---|---|---|
| **18s RESET** + **28s RESET** | ~**3 s** | Open timing menu (see [Timing menu guide](user_guide_timing_menu.md)). |

---

## Quick reference — STOP mode

| Control | Short | Long / hold | Combo |
|---|---|---|---|
| **START/STOP** | Toggle all clocks | ~3 s from stopped → reload period | +**28s** ~3 s full reset; +**RETURN** ~3 s reload period keep shot/excl |
| **+ HOME / + AWAY** | Goal; stop all; shot 28; clear excl | — | — |
| **− HOME / − AWAY** | Score −1 | — | — |
| **28s RESET** | Shot 28; clear excl | — | with **18s** → menu; with **S/S** → full reset |
| **18s RESET** | Shot → 18 if &lt; 18 | — | with **28s** → menu |
| **FORCE 18** | Shot 18; stop all | — | — |
| **EXCL** | Arm excl 1 then 2; stop all | — | — |
| **TIMEOUT** | Start TO | — | — |
| **INTERVAL** | Next period + IN/HT | — | — |
| **RETURN** | End TO/IN silent | ~3 s buzzer (+ end TO/IN) | with **S/S** → period reload |
| **GAME ±** | ±1 s period | +10 / −30 s | — |
| **SHOT ±** | ±1 s shot | ±10 s | — |

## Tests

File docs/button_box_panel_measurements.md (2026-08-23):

# Button-box faceplate — 3D print measurements

Dimensioned layout for a printable / CNC / laser faceplate matching [`button_box_panel.png`](button_box_panel.png).

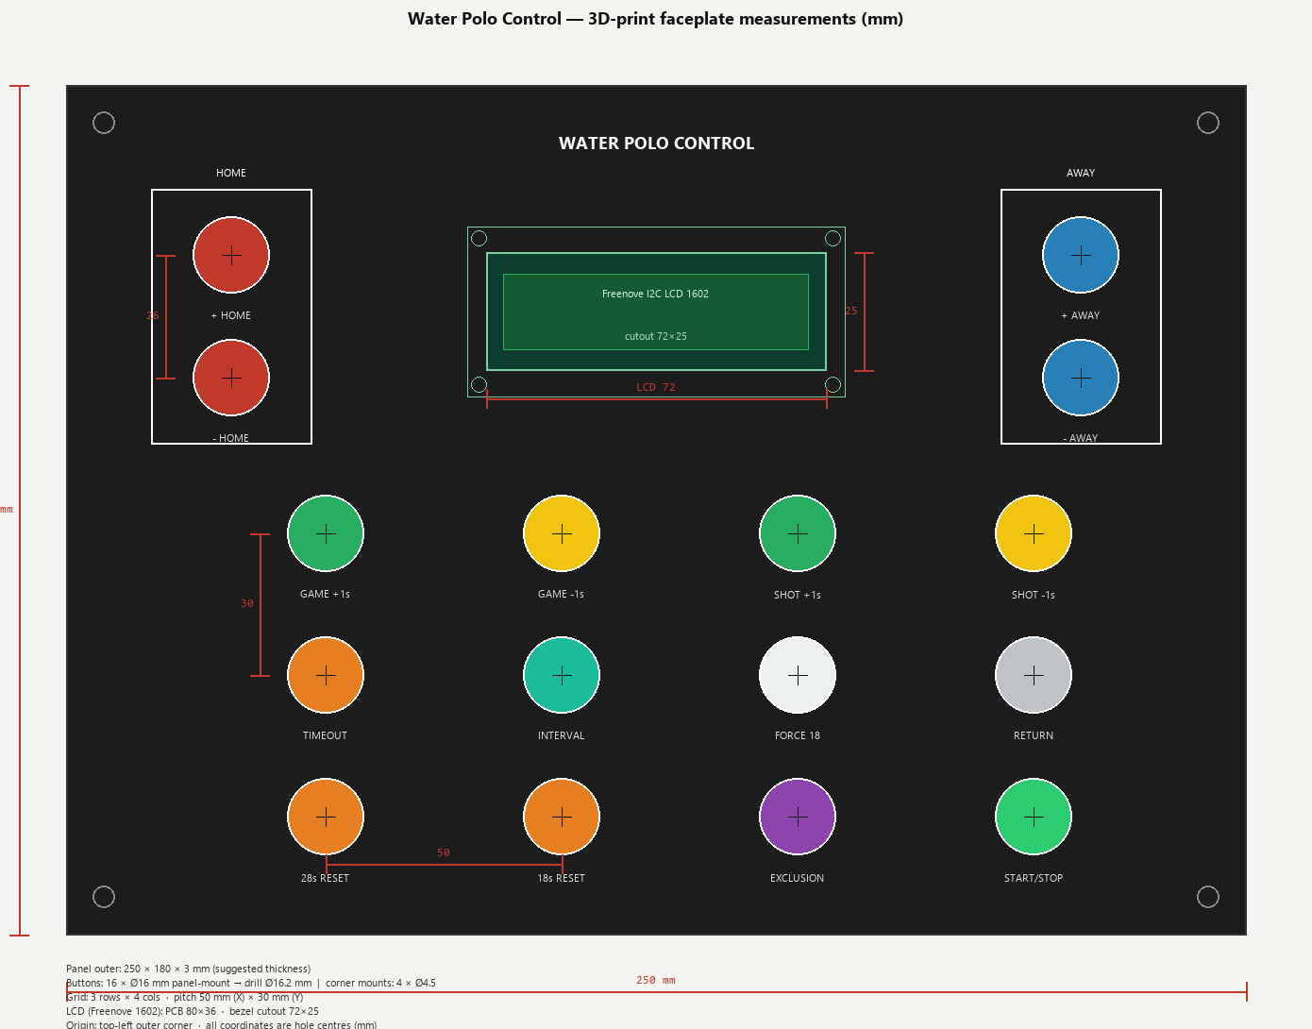
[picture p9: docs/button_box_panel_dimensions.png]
Dimensioned faceplate


Print guide overview:

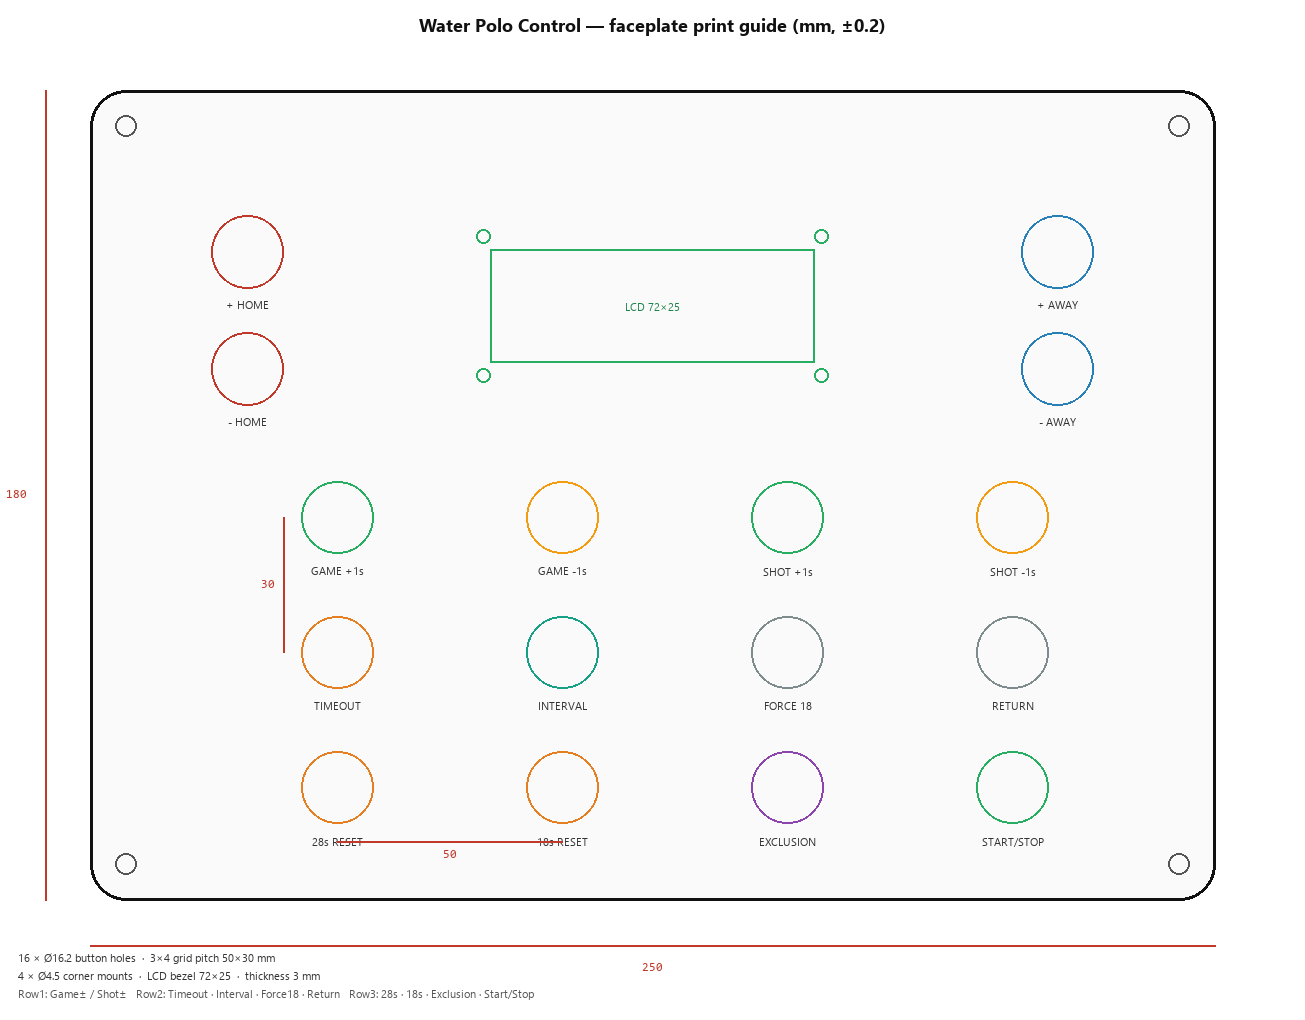
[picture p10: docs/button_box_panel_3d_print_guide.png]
3D print measurement guide


Vector (1:1 mm): [`button_box_panel_dimensions.svg`](button_box_panel_dimensions.svg)

## Layout (below LCD)

Three rows of four buttons (left → right):

| Row | Buttons |
|-----|---|
| 1 | Game Clock **+1s** · Game Clock **−1s** · Shot Clock **+1s** · Shot Clock **−1s** |
| 2 | **TIMEOUT** · **INTERVAL** · **FORCE 18** · **RETURN** |
| 3 | **28s RESET** · **18s RESET** · **EXCLUSION** · **START/STOP** |

HOME / AWAY score buttons and the Freenove LCD stay in the top band.

## 3D print files

| File | Format | Notes |
|---|---|---|
| [`button_box_panel_faceplate.stl`](button_box_panel_faceplate.stl) | STL | Ready for slicer (Cura / PrusaSlicer / Bambu) |
| [`button_box_panel_faceplate.obj`](button_box_panel_faceplate.obj) | OBJ | Same geometry |

Regenerate mesh:

```bash
python docs/generate_panel_stl.py
```

Print flat on the bed, **3 mm** thick, no supports. Ream button holes to Ø16.2 if the slicer shrinks circles.

## Design basis

| Item | Spec |
|---|---|
| Momentary buttons | **Ø16 mm** panel-mount (**16** pcs) |
| Button panel holes | **Ø16.2 mm** (0.2 mm clearance) |
| Display | **Freenove I2C IIC LCD 1602** (FNK0079) |
| Faceplate outer | **250 × 180 mm**, corner R **8** |
| Suggested thickness | **3 mm** (PLA/PETG); leave ≥18 mm depth behind for LCD + I2C backpack |
| Grid pitch | **50 mm** (X) × **30 mm** (Y) |
| Coordinate origin | Outer **top-left** corner of panel |

## Freenove LCD 1602 cutout

Classic I2C 1602 module (Freenove FNK0079 class):

| Feature | Size (mm) |
|---|---|
| PCB outline (behind panel) | 80 × 36 |
| **Front bezel cutout** (through faceplate) | **72 × 25** |
| Viewing area (reference) | 64.5 × 16.0 |
| Mounting-hole centres | **75 × 31** |
| Mounting-hole drill | Ø3.2 (M3 clear) |
| Module centre on panel | (125, 48) |
| Bezel cutout top-left | (89.0, 35.5) |

> Measure your module before final print: some Freenove boards are ~80×36, others closer to ~86×36. Adjust the bezel cutout if your metal frame differs; keep the **75×31** mount pattern unless your PCB says otherwise.

## Hole centre table (mm)

| Control | X | Y | Hole |
|---|--:|--:|---|
| + HOME | 35.0 | 36.0 | Ø16.2 |
| - HOME | 35.0 | 62.0 | Ø16.2 |
| + AWAY | 215.0 | 36.0 | Ø16.2 |
| - AWAY | 215.0 | 62.0 | Ø16.2 |
| GAME +1s | 55.0 | 95.0 | Ø16.2 |
| GAME -1s | 105.0 | 95.0 | Ø16.2 |
| SHOT +1s | 155.0 | 95.0 | Ø16.2 |
| SHOT -1s | 205.0 | 95.0 | Ø16.2 |
| TIMEOUT | 55.0 | 125.0 | Ø16.2 |
| INTERVAL | 105.0 | 125.0 | Ø16.2 |
| FORCE 18 | 155.0 | 125.0 | Ø16.2 |
| RETURN | 205.0 | 125.0 | Ø16.2 |
| 28s RESET | 55.0 | 155.0 | Ø16.2 |
| 18s RESET | 105.0 | 155.0 | Ø16.2 |
| EXCLUSION | 155.0 | 155.0 | Ø16.2 |
| START/STOP | 205.0 | 155.0 | Ø16.2 |
| LCD mount 1 | 87.5 | 32.5 | Ø3.2 |
| LCD mount 2 | 162.5 | 32.5 | Ø3.2 |
| LCD mount 3 | 87.5 | 63.5 | Ø3.2 |
| LCD mount 4 | 162.5 | 63.5 | Ø3.2 |
| Panel screw 1 | 8.0 | 8.0 | Ø4.5 |
| Panel screw 2 | 242.0 | 8.0 | Ø4.5 |
| Panel screw 3 | 8.0 | 172.0 | Ø4.5 |
| Panel screw 4 | 242.0 | 172.0 | Ø4.5 |

## Useful pitches (centre-to-centre)

| Pair | Pitch |
|---|---:|
| HOME + to − (vertical) | 26 mm |
| AWAY + to − (vertical) | 26 mm |
| Grid columns (adjacent) | 50 mm |
| Grid rows (adjacent) | 30 mm |

## 3D-print notes

1. Print faceplate face-up; use **0.2 mm** layer height for clean holes.
2. Drill/ream **all** button holes to **Ø16.2** after printing if your slicer undersizes circles (including START/STOP).
3. LCD sits from the **rear**; bezel shows through the 72×25 window; secure with 4× M3.
4. Labels can be engraved, vinyl, or a second printed legend layer.

## Regenerate drawings

```bash
python docs/generate_panel_dimensions.py
```

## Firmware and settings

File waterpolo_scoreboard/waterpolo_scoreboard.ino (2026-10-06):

/*
 * Water Polo Scoreboard
 * Board: Arduino Mega 2560
 * Display: Waveshare RGB-Matrix-P3-64x32 (SKU 33840, HUB75)
 * Mirror: Freenove I2C IIC LCD 1602 (16x2) on Mega SDA/SCL
 * Remote shot clocks: LoRa TX via Serial1 (same protocol as lora_remote)
 * PC link (optional): WaterPoloScoreBoard streams display frames over USB
 *   Serial @ 9600 every 0.25 s — "HH,AA,PERIOD,CLOCK,SHOT,EX1,EX2".
 *   The first valid frame switches to PC-driven mode (buttons + local clocks
 *   off until reset); the shot value is relayed to LoRa remotes, and keyword
 *   lines (BUZZER, END, CHANGE, TEST, exit) are forwarded unchanged.
 *
 * Matrix driver: Waveshare RGBmatrixPanel + Adafruit_GFX vendored in this
 * folder. Call Reginit() before matrix.begin().
 *
 * Libraries (Library Manager):
 *   - LiquidCrystal I2C (e.g. Frank de Brabander / Freenove zip)
 *
 * Buttons (active LOW, internal pull-ups — wire other side to GND):
 *   D2  = period clock start / stop
 *   D3  = force shot clock to 18 s (always; pauses period clock)
 *   D4  = exclusion (18 s, no reset) — 1st press clock 1, 2nd press clock 2
 *   D5  = shot clock set to 18 s if < 18 (preserves running/stopped state)
 *   D6  = shot → 28 (preserves period clock running/stopped state; clears exclusions)
 *   D7  = timeout 1:00 (pauses period+shot; independent countdown)
 *   D8  = interval (reloads match period length + shot 28; advances period 1→4;
 *         keeps remaining exclusions; after period 2 uses HALF_TIME_SECONDS,
 *         else INTERVAL_SECONDS)
 *   D35 = RETURN — short: end TO/IN early (no horn); long ~3 s: end TO/IN with
 *         buzzer (relay + LoRa). Not in TO/IN: long press is buzzer only.
 *         Also exits the timing menu.
 *   D36 = period +1 s (long press +10 s); in timing menu +30 s (shot pages ±1 s)
 *   D37 = period -1 s (long press -30 s); in timing menu -30 s (shot pages ±1 s)
 *   D38 = shot +1 s (long press +10 s)
 *   D39 = shot -1 s (long press -10 s)
 *   D40 = home score +  (also stops period clock, shot → 28, clears exclusions)
 *   D41 = home score -
 *   D42 = away score +  (also stops period clock, shot → 28, clears exclusions)
 *   D43 = away score -
 *
 * Relay output: D12 drives a 5V relay (HIGH = energised by default)
 * LoRa: Serial1 @ LORA_BAUD — Mega TX1=18 / RX1=19
 *
 * Shot clock runs while play is active (D2 / START in play mode).
 * In CLOCK=RUN menu mode the period may keep running while shot/exclusions are stopped.
 * When period remaining is less than the shot clock, the shot clock shows
 * (and follows) the period remaining — including when PERIOD_SECONDS /
 * match length is shorter than a full shot (e.g. 28 s).
 * At shot = 0: LoRa BUZZER, stop play (period keeps in RUN mode), reset shot to 28 s.
 * Exclusions: STOP and RUN follow shot/play; RUN-NS follows the period clock.
 * Remaining exclusion time is kept across INTERVAL / half-time into the next period.
 * A goal (home+ / away+) or D6 (shot → 28) clears both exclusion clocks.
 * Period counter P1–P4 advances on INTERVAL; half-time after P2 (display HT).
 * When the period clock hits 0: auto-start IN/HT for P1–P3; P4 stays at 0:00.
 * Period length defaults to PERIOD_SECONDS (8:00). Adjusting the period clock
 * before the first START of that period updates the match length carried to
 * later periods (INTERVAL / D2 long-press reload).
 *
 * D2 short press: start/stop immediately (play mode only).
 * Hold D2 ~3 s (STOP mode, from stopped): resets period clock to match length.
 * Hold D2 ~3 s (RUN mode): stops the period clock (and play).
 * Hold D2 + D35 ~3 s: reload period to match length; keeps shot + exclusions.
 * Hold D2 + D6 together for 3 s: full reset (scores, clocks, exclusions → defaults).
 * Hold D5 + D6 ~3 s: timing menu (PERIOD → INTERVAL → HALFTIME → TIMEOUT →
 *   SHOT 28 → SHOT 18 → CLOCK).
 *   D36 / D37 = ±30 s, shot pages ±1 s, CLOCK page: cycle STOP/RUN/RUN-NS.
 *   D2 = next / confirm · D35 exit.
 * D35 short: silent return from TO/IN. Hold D35 ~3 s: buzzer; also returns if in TO/IN.
 *
 * CLOCK menu: STOP (default) = D2 toggles period + shot + exclusions together.
 * RUN = first D2 of quarter (or after timeout) starts period + play; later D2 toggles
 * shot + exclusions only while period keeps running (timeout still stops period).
 * RUN-NS = same period behaviour as RUN but shot clock disabled (hidden, no tick/expiry).
 * Long D2 in RUN/RUN-NS stops the period; D2+D35 reloads period length without clearing shot/excl.
 */

#include <Wire.h>
#include <LiquidCrystal_I2C.h>
#include "RGBmatrixPanel.h"
#include "Adafruit_GFX.h"

// ----- Button pins -----
const uint8_t PIN_CLOCK_TOGGLE = 2;
const uint8_t PIN_SHOT_FORCE18 = 3;   // force shot → 18
const uint8_t PIN_EXCL         = 4;   // exclusion: 1st press clock 1, 2nd press clock 2
const uint8_t PIN_SHOT_18      = 5;   // → 18 s if < 18
const uint8_t PIN_SHOT_RESET   = 6;   // → 28 s
const uint8_t PIN_TIMEOUT      = 7;   // 1:00 timeout
const uint8_t PIN_INTERVAL     = 8;   // between-period break (HT after P2)
const uint8_t PIN_RELAY        = 12;  // 5 V relay coil / module IN
const uint8_t PIN_RETURN       = 35;  // short: end TO/IN; long 3 s: buzzer (+ return)
const uint8_t PIN_PERIOD_INC   = 36;  // period +1 s (long +10 s)
const uint8_t PIN_PERIOD_DEC   = 37;  // period -1 s (long -30 s)
const uint8_t PIN_SHOT_INC     = 38;  // shot +1 s
const uint8_t PIN_SHOT_DEC     = 39;  // shot -1 s
const uint8_t PIN_HOME_INC     = 40;
const uint8_t PIN_HOME_DEC     = 41;
const uint8_t PIN_AWAY_INC     = 42;
const uint8_t PIN_AWAY_DEC     = 43;

// true  = HIGH energises relay (bare transistor driver / many modules)
// false = LOW energises relay (common optocoupler relay boards marked LOW)
const bool RELAY_ACTIVE_HIGH = true;

// ----- HUB75 pins (working Waveshare 64x32 — do not swap LAT/OE) -----
// R1 D24  G1 D25  B1 D26  R2 D27  G2 D28  B2 D29  (PORTA, fixed by lib)
// Ribbon: yellow #14 → LAT D9,  green #15 → OE D10,  orange #13 → CLK D11
#define CLK 11
#define OE  10
#define LAT  9
#define A   A0
#define B   A1
#define C   A2
#define D   A3

const bool MATRIX_DOUBLE_BUFFER = true;
const uint8_t MATRIX_BRIGHT = 3;
RGBmatrixPanel matrix(A, B, C, D, CLK, LAT, OE, MATRIX_DOUBLE_BUFFER, 64);
uint16_t COL_HOME, COL_AWAY, COL_CLOCK, COL_SHOT, COL_LABEL, COL_DIM, COL_EXCL;

// Dead columns on some panels (49–52). Keep UI left of this.
const int MATRIX_SAFE_WIDTH = 49;

// Waveshare panel register init — MUST run before matrix.begin()
void Reginit()
{
  pinMode(24, OUTPUT); // R1
  pinMode(25, OUTPUT); // G1
  pinMode(26, OUTPUT); // B1

  pinMode(27, OUTPUT); // R2
  pinMode(28, OUTPUT); // G2
  pinMode(29, OUTPUT); // B2

  pinMode(CLK, OUTPUT);
  pinMode(OE, OUTPUT);
  pinMode(LAT, OUTPUT);

  digitalWrite(OE, HIGH);
  digitalWrite(LAT, LOW);
  digitalWrite(CLK, LOW);

  int MaxLed = 64;

  int C12[16] =
  {
    0, 1, 1, 1,
    1, 1, 1, 1,
    1, 1, 1, 1,
    1, 1, 1, 1
  };

  int C13[16] =
  {
    0, 0, 0, 0,
    0, 0, 0, 0,
    0, 1, 0, 0,
    0, 0, 0, 0
  };

  for (int l = 0; l < MaxLed; l++)
  {
    int y = l % 16;

    digitalWrite(24, LOW);
    digitalWrite(25, LOW);
    digitalWrite(26, LOW);
    digitalWrite(27, LOW);
    digitalWrite(28, LOW);
    digitalWrite(29, LOW);

    if (C12[y] == 1)
    {
      digitalWrite(24, HIGH);
      digitalWrite(25, HIGH);
      digitalWrite(26, HIGH);
      digitalWrite(27, HIGH);
      digitalWrite(28, HIGH);
      digitalWrite(29, HIGH);
    }

    if (l > MaxLed - 12)
      digitalWrite(LAT, HIGH);
    else
      digitalWrite(LAT, LOW);

    digitalWrite(CLK, HIGH);
    delayMicroseconds(2);
    digitalWrite(CLK, LOW);
  }

  digitalWrite(LAT, LOW);
  digitalWrite(CLK, LOW);

  for (int l = 0; l < MaxLed; l++)
  {
    int y = l % 16;

    digitalWrite(24, LOW);
    digitalWrite(25, LOW);
    digitalWrite(26, LOW);
    digitalWrite(27, LOW);
    digitalWrite(28, LOW);
    digitalWrite(29, LOW);

    if (C13[y] == 1)
    {
      digitalWrite(24, HIGH);
      digitalWrite(25, HIGH);
      digitalWrite(26, HIGH);
      digitalWrite(27, HIGH);
      digitalWrite(28, HIGH);
      digitalWrite(29, HIGH);
    }

    if (l > MaxLed - 13)
      digitalWrite(LAT, HIGH);
    else
      digitalWrite(LAT, LOW);

    digitalWrite(CLK, HIGH);
    delayMicroseconds(2);
    digitalWrite(CLK, LOW);
  }

  digitalWrite(LAT, LOW);
  digitalWrite(CLK, LOW);
}

// ----- Freenove I2C LCD 1602 (SDA=20, SCL=21 on Mega) -----
LiquidCrystal_I2C lcd(0x27, 16, 2);

bool i2CAddrTest(uint8_t addr) {
  Wire.beginTransmission(addr);
  return (Wire.endTransmission() == 0);
}

void initI2cLcd() {
  Wire.begin();
  if (!i2CAddrTest(0x27)) {
    lcd = LiquidCrystal_I2C(0x3F, 16, 2);
  }
  lcd.init();
  lcd.backlight();
  lcd.clear();
}

// ----- LoRa (Serial1) -----
const unsigned long LORA_BAUD = 9600;
const int LORA_AUX_PIN = -1;

// ---------------------------------------------------------------------------
// LoRa CHANNEL CONFIGURATION (same table as lora_remote)
// ---------------------------------------------------------------------------
const long LORA_CHANNEL_FREQS[] = {
  433050000L,  // CH0  433.050 MHz
  433100000L,  // CH1  433.100 MHz
  433150000L,  // CH2  433.150 MHz
  433200000L   // CH3  433.200 MHz
};
const uint8_t LORA_CHANNEL_COUNT =
    sizeof(LORA_CHANNEL_FREQS) / sizeof(LORA_CHANNEL_FREQS[0]);
const uint8_t LORA_DEFAULT_CHANNEL = 2;  // 433.150 MHz

// Pool link: ~30 m, over water, bodies in the path.
// SF7 keeps shot-clock packets well under the 0.5 s resend window.
// 22 dBm is module max — fade margin through water and people, not range.
const uint8_t LORA_SPREAD_FACTOR = 7;   // SF5–12; 7 = fast, plenty for 30 m
const uint8_t LORA_TX_POWER_DBM  = 22;  // 0–22 dBm; 22 = max punch through bodies

// USB Serial (9600) logs AT commands, TX packets, and any module UART replies.
const bool LORA_TX_LOG = false;

// ----- Scoreboard state -----
const int PERIOD_SECONDS     = 8 * 60;       // 8:00 default match period length
const int INTERVAL_SECONDS   = 2 * 60;       // default between P1–P2 and P3–P4
const int HALF_TIME_SECONDS  = 2 * 60;       // default after P2 (official half-time is 5:00)
const int TIMEOUT_SECONDS    = 60;           // default timeout
const int PERIOD_MAX         = 4;            // P1–P4
const int SHOT_FULL          = 28;           // default 28s RESET length
const int SHOT_PARTIAL       = 18;           // default 18s RESET / FORCE 18
const int EXCLUSION_SECONDS  = 18;

const int MENU_STEP_SECONDS    = 30;
const int PERIOD_MENU_MIN      = 30;
const int PERIOD_MENU_MAX      = 15 * 60;
const int INTERVAL_MENU_MIN    = 0;
const int INTERVAL_MENU_MAX    = 3 * 60;
const int HALF_TIME_MENU_MIN   = 0;
const int HALF_TIME_MENU_MAX   = 7 * 60;
const int TIMEOUT_MENU_MIN     = 30;
const int TIMEOUT_MENU_MAX     = 5 * 60;
const int SHOT_MENU_MIN        = 1;
const int SHOT_MENU_MAX        = 60;
const uint8_t MENU_ITEM_PERIOD    = 0;
const uint8_t MENU_ITEM_INTERVAL  = 1;
const uint8_t MENU_ITEM_HALFTIME = 2;
const uint8_t MENU_ITEM_TIMEOUT   = 3;
const uint8_t MENU_ITEM_SHOT28    = 4;
const uint8_t MENU_ITEM_SHOT18    = 5;
const uint8_t MENU_ITEM_CLOCK     = 6;
const uint8_t MENU_ITEM_COUNT     = 7;

int homeScore = 0;
int awayScore = 0;
int periodNum = 1;         // current period 1–PERIOD_MAX
int periodLength = PERIOD_SECONDS;  // carried match length (set before first START)
int intervalLength = INTERVAL_SECONDS;
int halfTimeLength = HALF_TIME_SECONDS;
int timeoutLength = TIMEOUT_SECONDS;
int shotFull = SHOT_FULL;          // 28s RESET / goal / expiry reload
int shotPartial = SHOT_PARTIAL;    // 18s RESET (if shorter) / FORCE 18
int secondsLeft = PERIOD_SECONDS;
int shotLeft = SHOT_FULL;
int timeoutLeft = 0;       // >0 = timeout mode
int intervalLeft = 0;      // >0 = interval / half-time mode
int excl1Left = 0;         // 0 = inactive; cannot restart while >0
int excl2Left = 0;
int lastShotSent = -1;
bool clockRunning = false;     // play: shot (exclusions follow period in RUN / RUN-NS)
bool periodRunning = false;    // main period countdown (may run without play in RUN mode)
const uint8_t CLOCK_MODE_STOP   = 0;
const uint8_t CLOCK_MODE_RUN    = 1;
const uint8_t CLOCK_MODE_RUN_NS = 2;
uint8_t clockMode = CLOCK_MODE_STOP;  // menu CLOCK: STOP / RUN / RUN-NS
bool intervalIsHalfTime = false;
bool periodStarted = false;  // true after first START of current period

bool inSettingsMenu = false;
uint8_t menuItem = 0;          // 0 PERIOD · 1 INTERVAL · 2 HALFTIME · 3 TIMEOUT · 4 CLOCK

// ----- PC link (USB Serial from WaterPoloScoreBoard) -----
// Frame every 0.25 s: HH,AA,PERIOD,CLOCK,SHOT,EX1,EX2   e.g. "03,01,P2,245,18,12,0"
// PERIOD = P1–P4, or TO / IN / HT with CLOCK = break countdown (seconds).
// Other lines (BUZZER, END, CHANGE, TEST, exit) are relayed to LoRa.
// First valid frame latches pcDriven until reset: buttons and local clocks stop.
const uint8_t PC_BREAK_NONE = 0;
const uint8_t PC_BREAK_TO   = 1;
const uint8_t PC_BREAK_IN   = 2;
const uint8_t PC_BREAK_HT   = 3;
const uint8_t PC_FRAME_FIELDS = 7;
const uint32_t PC_LINK_TIMEOUT_MS = 2000;  // stop LoRa shot resends when frames stop

bool pcDriven = false;
uint8_t pcBreak = PC_BREAK_NONE;
uint32_t lastPcFrameMs = 0;
char pcLine[48];
uint8_t pcLineLen = 0;
bool pcLineOverflow = false;
char lastPcFrame[48] = "";

bool inTimeout() { return pcDriven ? pcBreak == PC_BREAK_TO : timeoutLeft > 0; }
bool inInterval() {
  return pcDriven ? (pcBreak == PC_BREAK_IN || pcBreak == PC_BREAK_HT) : intervalLeft > 0;
}
bool inPlay() { return !inTimeout() && !inInterval() && !inSettingsMenu; }
bool inMenu() { return inSettingsMenu; }

void markDirty();
void setShotClock(int value);
void syncShotWithPeriod();
void ackCommand();
void drawLcd();
void serviceLcdAck();
void clearExclusions();
bool startNextExclusion();
void enterSettingsMenu();
void exitSettingsMenu();
void adjustMenuValue(int delta);
void serviceMenuCombo(uint32_t now);
void forwardToLoRa(const char *command);
void pulseRelay(uint16_t durationMs);
void pollPcSerial();
void servicePcLoRaResend();
void soundBuzzer();
void endTimeoutOrInterval();
void serviceReturnLongPress(uint32_t now);
void stopAllClocks();
void stopPlayClocks();
void startPlayClocks(uint32_t now);
void toggleClockToggle(uint32_t now);
bool menuIsClockItem();
bool menuIsShotItem();
void toggleClockMode();
const char *menuClockLabel();
bool isRunningClock();
bool shotClockEnabled();
bool exclTicking();
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
void loop() {
  pollLoRaModuleEcho();
  pollPcSerial();
  pollButtons();
  updateClocks();
  serviceRelay();
  serviceLcdAck();
  pollButtons();

  if (pcDriven) {
    servicePcLoRaResend();
  } else if (inPlay() && clockRunning && shotClockEnabled() &&
             (millis() - lastLoRaResendMs >= LORA_RESEND_MS)) {
    sendShotToLoRa(shotLeft, true);
  }

  pollButtons();

  bool needsBlink = false;
  if (!inSettingsMenu) {
    int mainSec = secondsLeft;
    if (inTimeout()) mainSec = timeoutLeft;
    else if (inInterval()) mainSec = intervalLeft;
    needsBlink = (mainSec == 0) || (shotClockEnabled() && shotLeft == 0);
  }
  if (displayDirty || (needsBlink && (millis() - lastDrawMs >= 400UL))) {
    drawMatrix();
    lastDrawMs = millis();
    displayDirty = false;
  }
}

// ---------------------------------------------------------------------------
// Inputs
// ---------------------------------------------------------------------------

void pollButtons() {
  if (pcDriven) return;
  uint32_t now = millis();

  for (uint8_t i = 0; i < BTN_COUNT; i++) {
    bool raw = digitalRead(buttons[i].pin);
    if (raw != buttons[i].lastRaw) {
      buttons[i].lastRaw = raw;
      buttons[i].lastChangeMs = now;
    }
    if ((now - buttons[i].lastChangeMs) < DEBOUNCE_MS) continue;
    if (raw == buttons[i].stable) continue;

    bool was = buttons[i].stable;
    buttons[i].stable = raw;

    if (was == HIGH && raw == LOW) {
      onButtonPress(buttons[i].pin, now);
    }
    if (was == LOW && raw == HIGH) {
      onButtonRelease(buttons[i].pin, now);
    }
  }

  if (buttons[0].stable == LOW && !clockLongHandled &&
      clockBtnDownMs != 0 && (now - clockBtnDownMs) >= LONG_PRESS_MS) {
    // Skip if D6 or D35 also held — those are combo paths
    if (!inSettingsMenu && !buttonIsDown(PIN_SHOT_RESET) &&
        !buttonIsDown(PIN_RETURN) && inPlay()) {
      if (isRunningClock()) {
        // RUN: long press stops the period clock
        if (clockWasPeriodRunningAtPress || periodRunning) {
          stopAllClocks();
          clockPendingStartPlay = false;
          clockLongHandled = true;
          ackCommand();
        }
      } else if (!clockWasPeriodRunningAtPress) {
        // STOP: from stopped → reload period to match length
        stopAllClocks();
        secondsLeft = periodLength;
        syncShotWithPeriod();
        clockLongHandled = true;
        ackCommand();
      }
    }
  }

  serviceAdjustLongPress(now);
  serviceReturnLongPress(now);
  serviceComboReset(now);
  servicePeriodReloadCombo(now);
  serviceMenuCombo(now);
}

void onButtonPress(uint8_t pin, uint32_t now) {
  if (inSettingsMenu) {
    switch (pin) {
      case PIN_CLOCK_TOGGLE:
        menuItem++;
        if (menuItem >= MENU_ITEM_COUNT) {
          exitSettingsMenu();
        } else {
          ackCommand();
        }
        break;
      case PIN_PERIOD_INC:
      case PIN_PERIOD_DEC:
        if (menuIsClockItem()) {
          toggleClockMode();
        } else if (menuIsShotItem()) {
          adjustMenuValue((pin == PIN_PERIOD_INC) ? 1 : -1);
        } else if (pin == PIN_PERIOD_INC) {
          adjustMenuValue(MENU_STEP_SECONDS);
        } else {
          adjustMenuValue(-MENU_STEP_SECONDS);
        }
        break;
      case PIN_RETURN:
        exitSettingsMenu();
        break;
      default:
        break;
    }
    return;
  }

  switch (pin) {
    case PIN_CLOCK_TOGGLE:
      // Start/stop only in play mode (not during TO/IN)
      if (!inPlay()) break;
      // If D6 already held, this is starting a combo-reset — don't toggle
      if (buttonIsDown(PIN_SHOT_RESET)) {
        clockBtnDownMs = now;
        clockLongHandled = false;
        clockPendingStartPlay = false;
        clockWasRunningAtPress = clockRunning;
        clockWasPeriodRunningAtPress = periodRunning;
        break;
      }
      // If D35 already held, this is period-reload combo — don't toggle
      if (buttonIsDown(PIN_RETURN)) {
        clockBtnDownMs = now;
        clockLongHandled = false;
        clockPendingStartPlay = false;
        clockWasRunningAtPress = clockRunning;
        clockWasPeriodRunningAtPress = periodRunning;
        break;
      }
      // D6/D5 must not change run state — drop ghost D2 edges after those buttons
      if ((int32_t)(now - ignoreClockToggleUntilMs) < 0) break;
      clockBtnDownMs = now;
      clockLongHandled = false;
      clockPendingStartPlay = false;
      clockWasRunningAtPress = clockRunning;
      clockWasPeriodRunningAtPress = periodRunning;
      if (isRunningClock() && periodRunning) {
        // Period already live: stop play immediately if running; if play was
        // already stopped, defer start until release (so long press can stop period)
        if (clockRunning) {
          stopPlayClocks();
          ackCommand();
        } else {
          clockPendingStartPlay = true;
        }
      } else {
        toggleClockToggle(now);
        ackCommand();
      }
      break;
    case PIN_HOME_INC:
      homeScore = min(99, homeScore + 1);
      stopPlayClocks();
      clearExclusions();
      if (shotClockEnabled()) setShotClock(shotFull);
      ackCommand();
      break;
    case PIN_AWAY_INC:
      awayScore = min(99, awayScore + 1);
      stopPlayClocks();
      clearExclusions();
      if (shotClockEnabled()) setShotClock(shotFull);
      ackCommand();
      break;
    case PIN_HOME_DEC:
      if (homeScore > 0) {
        homeScore--;
        ackCommand();
      }
      break;
    case PIN_AWAY_DEC:
      if (awayScore > 0) {
        awayScore--;
        ackCommand();
      }
      break;
    case PIN_SHOT_RESET: {
      // If D2 already held, this is starting a combo-reset — don't change shot
      if (buttonIsDown(PIN_CLOCK_TOGGLE)) break;
      // D5 already down → timing-menu combo; wait for hold, don't fire 28
      if (buttonIsDown(PIN_SHOT_18)) {
        pendingShot18 = false;
        pendingShot28 = false;
        break;
      }
      pendingShot28 = true;
      break;
    }
    case PIN_SHOT_18: {
      // D6 already down → timing-menu combo
      if (buttonIsDown(PIN_SHOT_RESET)) {
        pendingShot18 = false;
        pendingShot28 = false;
        break;
      }
      pendingShot18 = true;
      break;
    }
    case PIN_PERIOD_INC:
    case PIN_PERIOD_DEC:
    case PIN_SHOT_INC:
    case PIN_SHOT_DEC:
      if ((pin == PIN_SHOT_INC || pin == PIN_SHOT_DEC) && !shotClockEnabled()) break;
      // Short = ±1 on release; long = ±10/±30 while held
      adjustPinDown = pin;
      adjustDownMs = now;
      adjustLongHandled = false;
      break;
    case PIN_TIMEOUT:
      startTimeout();
      ackCommand();
      break;
    case PIN_INTERVAL:
      startInterval();
      ackCommand();
      break;
    case PIN_SHOT_FORCE18:
      if (!shotClockEnabled()) break;
      stopPlayClocks();
      setShotClock(shotPartial);
      ackCommand();
      break;
    case PIN_RETURN:
      // If D2 already held, this is period-reload combo — don't start RETURN actions
      if (buttonIsDown(PIN_CLOCK_TOGGLE)) {
        returnBtnDownMs = now;
        returnLongHandled = false;
        break;
      }
      // Short vs long decided on hold/release — do not return yet
      returnBtnDownMs = now;
      returnLongHandled = false;
      break;
    case PIN_EXCL:
      if (!startNextExclusion()) break;
      stopPlayClocks();
      if (shotClockEnabled() && shotLeft < shotPartial) {
        setShotClock(shotPartial);
      }
      ackCommand();
      break;
  }
}
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

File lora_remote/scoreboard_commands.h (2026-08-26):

#ifndef SCOREBOARD_COMMANDS_H
#define SCOREBOARD_COMMANDS_H

#include <Arduino.h>

const int buzzerPin = 10;

const int SEG_A = 8;
const int SEG_B = 7;
const int SEG_C = 6;
const int SEG_D = 5;
const int SEG_E = 4;
const int SEG_F = 3;
const int SEG_G = 2;
const int SEG_DP = 9;

const int SEG_1A = A6;
const int SEG_1B = A5;
const int SEG_1C = A4;
const int SEG_1D = A3;
const int SEG_1E = A2;
const int SEG_1F = A1;
const int SEG_1G = A0;
const int SEG_1DP = A7;

const uint8_t digits[10][7] = {
    {LOW, LOW, LOW, LOW, LOW, LOW, HIGH},
    {HIGH, LOW, LOW, HIGH, HIGH, HIGH, HIGH},
    {LOW, LOW, HIGH, LOW, LOW, HIGH, LOW},
    {LOW, LOW, LOW, LOW, HIGH, HIGH, LOW},
    {HIGH, LOW, LOW, HIGH, HIGH, LOW, LOW},
    {LOW, HIGH, LOW, LOW, HIGH, LOW, LOW},
    {LOW, HIGH, LOW, LOW, LOW, LOW, LOW},
    {LOW, LOW, LOW, HIGH, HIGH, HIGH, HIGH},
    {LOW, LOW, LOW, LOW, LOW, LOW, LOW},
    {LOW, LOW, LOW, LOW, HIGH, LOW, LOW},
};

const uint8_t digitstens[10][7] = {
    {HIGH, HIGH, HIGH, HIGH, HIGH, HIGH, HIGH},
    {HIGH, LOW, LOW, HIGH, HIGH, HIGH, HIGH},
    {LOW, LOW, HIGH, LOW, LOW, HIGH, LOW},
    {LOW, LOW, LOW, LOW, HIGH, HIGH, LOW},
    {HIGH, LOW, LOW, HIGH, HIGH, LOW, LOW},
    {LOW, HIGH, LOW, LOW, HIGH, LOW, LOW},
    {LOW, HIGH, LOW, LOW, LOW, LOW, LOW},
    {LOW, LOW, LOW, HIGH, HIGH, HIGH, HIGH},
    {LOW, LOW, LOW, LOW, LOW, LOW, LOW},
    {LOW, LOW, LOW, LOW, HIGH, LOW, LOW},
};

const int segPins[7] = {SEG_A, SEG_B, SEG_C, SEG_D, SEG_E, SEG_F, SEG_G};
const int segPinstens[7] = {SEG_1A, SEG_1B, SEG_1C, SEG_1D, SEG_1E, SEG_1F, SEG_1G};

inline void scoreboardSetupPins() {
  for (int i = 0; i < 7; i++) {
    pinMode(segPins[i], OUTPUT);
    digitalWrite(segPins[i], HIGH);
    pinMode(segPinstens[i], OUTPUT);
    digitalWrite(segPinstens[i], HIGH);
  }
  pinMode(SEG_DP, OUTPUT);
  pinMode(SEG_1DP, OUTPUT);
  digitalWrite(SEG_DP, HIGH);
  digitalWrite(SEG_1DP, HIGH);
  pinMode(buzzerPin, OUTPUT);
  digitalWrite(buzzerPin, LOW);
}

inline void showDigit(int n) {
  n = constrain(n, 0, 9);
  for (int i = 0; i < 7; i++) {
    digitalWrite(segPins[i], digits[n][i]);
  }
}

inline void showDigittens(int n) {
  n = constrain(n, 0, 9);
  for (int i = 0; i < 7; i++) {
    digitalWrite(segPinstens[i], digitstens[n][i]);
  }
}

inline void clearDisplay() {
  for (int i = 0; i < 7; i++) {
    digitalWrite(segPins[i], HIGH);
    digitalWrite(segPinstens[i], HIGH);
  }
  digitalWrite(SEG_DP, HIGH);
  digitalWrite(SEG_1DP, HIGH);
}

inline bool handleScoreboardCommand(const String& command, String* bleAckOut) {
  if (command == "TEST") {
    digitalWrite(SEG_DP, LOW);
    digitalWrite(buzzerPin, HIGH);
    delay(50);
    digitalWrite(buzzerPin, LOW);
    if (bleAckOut != nullptr) {
      *bleAckOut = "D10 TEST";
    }
    return true;
  }

  if (command == "BUZZER") {
    if (bleAckOut != nullptr) {
      *bleAckOut = "BUZZER";
    }
    digitalWrite(buzzerPin, HIGH);
    delay(500);
    digitalWrite(buzzerPin, LOW);
    delay(100);
    return true;
  }

  if (command == "CHANGE") {
    if (bleAckOut != nullptr) {
      *bleAckOut = "CHANGE";
    }
    digitalWrite(buzzerPin, HIGH);
    delay(1000);
    digitalWrite(buzzerPin, LOW);
    delay(100);
    clearDisplay();
    return true;
  }

  if (command == "END") {
    if (bleAckOut != nullptr) {
      *bleAckOut = "END";
    }
    digitalWrite(buzzerPin, HIGH);
    delay(1000);
    digitalWrite(buzzerPin, LOW);
    delay(100);
    clearDisplay();
    return true;
  }

  if (command == "exit") {
    if (bleAckOut != nullptr) {
      *bleAckOut = "exit";
    }
    clearDisplay();
    return true;
  }

  if (command == "0") {
    clearDisplay();
    return true;
  }

  if (command >= "1") {
    int n = command.toInt();
    int tens = n / 10;
    int ones = n % 10;
    showDigit(ones);
    showDigittens(tens);
    Serial.print(n);
    Serial.print(" tens :");
    Serial.print(tens);
    Serial.print(" ones :");
    Serial.println(ones);
    return true;
  }

  return false;
}

#endif

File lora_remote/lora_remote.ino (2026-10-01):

#include "scoreboard_commands.h"

const unsigned long LORA_BAUD = 9600;

// ---------------------------------------------------------------------------
// LoRa CHANNEL CONFIGURATION (same table as master)
// ---------------------------------------------------------------------------
// The DX-LR32 uses frequencies, not numbered channels.
// We define our own channel table for convenience.
//
// To change the LoRa channel later, simply edit LORA_DEFAULT_CHANNEL below.
// ---------------------------------------------------------------------------

const long LORA_CHANNEL_FREQS[] = {
  433050000,  // CH0
  433100000,  // CH1
  433150000,  // CH2
  433200000   // CH3
};

const uint8_t LORA_CHANNEL_COUNT =
    sizeof(LORA_CHANNEL_FREQS) / sizeof(long);

// ---------------------------------------------------------------------------
// SELECT WHICH CHANNEL THIS REMOTE SCOREBOARD SHOULD USE
// ---------------------------------------------------------------------------
// Change this number to switch channel:
//   0 = 433.050 MHz
//   1 = 433.100 MHz
//   2 = 433.150 MHz
//   3 = 433.200 MHz
//
// Example: set to channel 2 → 433.150 MHz
// ---------------------------------------------------------------------------
const uint8_t LORA_DEFAULT_CHANNEL = 2;

// Pool link: ~30 m, over water, bodies in the path. Must match the master.
const uint8_t LORA_SPREAD_FACTOR = 7;   // SF5–12; 7 = fast, plenty for 30 m
const uint8_t LORA_TX_POWER_DBM  = 22;  // 0–22 dBm; 22 = max punch through bodies

// ---------------------------------------------------------------------------
// Send AT commands to LoRa module
// ---------------------------------------------------------------------------
void forwardLoRaAT(const String& cmd) {
  Serial1.println(cmd);
  Serial.print("LoRa AT: ");
  Serial.println(cmd);
}

// ---------------------------------------------------------------------------
// Set LoRa channel (frequency)
// ---------------------------------------------------------------------------
void setLoRaChannel(uint8_t ch) {
  if (ch >= LORA_CHANNEL_COUNT) {
    Serial.print("Invalid LoRa channel: ");
    Serial.println(ch);
    return;
  }

  long freq = LORA_CHANNEL_FREQS[ch];
  String cmd = "AT+FREQ=" + String(freq);

  Serial.print("Setting LoRa channel ");
  Serial.print(ch);
  Serial.print(" (");
  Serial.print(freq);
  Serial.println(" Hz)");

  forwardLoRaAT(cmd);
}

void configureLoRa() {
  setLoRaChannel(LORA_DEFAULT_CHANNEL);
  delay(50);
  forwardLoRaAT("AT+SF" + String(LORA_SPREAD_FACTOR));
  delay(50);
  forwardLoRaAT("AT+POWE" + String(LORA_TX_POWER_DBM));
  delay(50);
}

// ---------------------------------------------------------------------------
// Setup
// ---------------------------------------------------------------------------
void setup() {
  scoreboardSetupPins();

  Serial.begin(9600);
  Serial1.begin(LORA_BAUD);
  Serial1.setTimeout(50);

  Serial.println("LoRa remote scoreboard ready");

  // -------------------------------------------------------------------------
  // SET CHANNEL / SF / POWER AT STARTUP (factory defaults, same as master)
  // -------------------------------------------------------------------------
  configureLoRa();
}

// ---------------------------------------------------------------------------
// Main loop
// ---------------------------------------------------------------------------
void loop() {
  if (!Serial1.available()) {
    return;
  }

  String command = Serial1.readStringUntil('\n');
  command.trim();
  if (command.length() == 0) {
    return;
  }

  Serial.print("LoRa RX: ");
  Serial.println(command);

  // Remote boards DO NOT change channel based on LoRa commands.
  // Only scoreboard commands are processed.
  handleScoreboardCommand(command, nullptr);
}

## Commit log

2026-08-10 matrix test
    [button_box_panel_faceplate.obj, button_box_panel_faceplate.stl]
2026-08-23 Updated with menu option.
    Add CLOCK (STOP/RUN) to the timing menu, running-clock D2 behaviour, RETURN buzzer and period-reload combos, operator guides, and refreshed 3x4 button panel docs.
    [button_box_panel_faceplate.obj, button_box_panel_faceplate.stl]
2026-09-01 added long and short shotclock
    [waterpolo_scoreboard.ino]
2026-09-02 Add P5 RGB matrix housing docs and diagrams.
2026-10-01 updated away colour
    Add the LoRa remote wiring guide and remove the old test_waveshare folder.
